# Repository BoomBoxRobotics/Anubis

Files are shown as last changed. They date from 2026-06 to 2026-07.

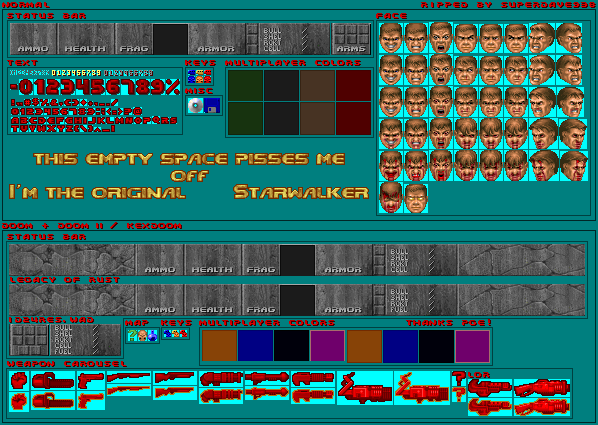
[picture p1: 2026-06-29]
Hosyond_apr24b/Games/Dungeon_Run_HUD.png

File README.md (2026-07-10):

# Anubis RC Controller Daughterboard

**A compact open-hardware support board for a DIY ESP32-S3 RC transmitter.**

Anubis is an open hardware and open firmware RC controller project built around accessible DIY parts, modern radio-control features, and a design that builders can understand, repair, modify, and improve.

This repository contains the custom daughterboard for the Anubis controller. It sits under a Hosyond 2.8 inch ESP32-S3 display board and turns the early wiring-heavy prototype into a cleaner, more repeatable hardware platform.

## Mission

The goal is simple: make a capable, repairable, hackable transmitter that is not locked behind a black box.

The first Anubis prototype used off-the-shelf modules wired together by hand: display board, power switches, regulators, analog input boards, GPIO expanders, gimbal connectors, and radio wiring. That is a great way to prove an idea, but it gets messy fast. This daughterboard pulls those support circuits onto a purpose-built PCB while leaving the Hosyond ESP32-S3 board as the main brain, display, touch interface, and firmware target.

Anubis is meant for experimentation as much as use. Builders should be able to change pin mappings, adapt connectors, swap radio hardware, and tune the firmware for their own transmitter layout.

## At A Glance

| Area | Current Direction |
| --- | --- |
| Main controller | Hosyond 2.8 inch ESP32-S3 display/dev board |
| Battery system | 2S LiPo or two 18650 cells as a 2S pack |
| Charging input | USB-C 5 V input, 500 mA to 1.5 A charge target |
| Switched outputs | `+5V_SW` and `+3V3_SW` accessory rails |
| Analog inputs | Two onboard ADS1115 ADCs, up to 8 analog channels |
| GPIO expansion | MCP23017 16-bit I2C GPIO expander |
| Radio paths | ELRS/CRSF over UART and optional ESP-NOW |
| Assembly goal | As much JLCPCB assembly as practical |
| Project status | Prototype hardware, ready for assembled-board validation |

## Core Design Goals

- Use common, hobby-accessible parts where possible.
- Keep the project open enough for community modification.
- Support modern RC workflows such as ELRS and ESP-NOW.
- Reduce hand wiring compared with the early prototype.
- Make the board practical for JLCPCB assembly.
- Keep external accessory power switchable from firmware.
- Leave room for manual wiring where real-world modules and harnesses vary.

## Hardware Overview

The daughterboard adds the support electronics around the Hosyond ESP32-S3 board:

- USB-C 5 V input for charging and power input.
- Standard 2S LiPo balance connector for the battery pack.
- Support for a 2S LiPo pack or two 18650 cells configured as a 2S pack.
- 2S battery gauge/protection circuitry based around `BQ28Z610DRZR-R1`.
- R14 high-side protection path using two JLC-available `CSD18502Q5B` N-FETs, with the charger and buck regulators fed from protected `BAT_SYS`.
- Switched 5 V rail for UART/ELRS-side accessories.
- Switched 3.3 V rail for I2C, analog, and low-voltage peripherals.
- Two Pololu mini pushbutton power switch modules for rail control.
- Two onboard ADS1115 ADC circuits for up to eight analog inputs.
- One onboard MCP23017 GPIO expander for buttons and digital expansion.
- JST and pin-header breakouts for UART, I2C, GPIO, gimbals, and accessories.
- ESD protection for external signal connections.
- Ground plane and wider routing rules for higher-current power paths.

## Power Rails

| Rail | Intended Use | Approximate Max Current |
| --- | --- | --- |
| USB-C input | 5 V charge/input source | 500 mA to 1.5 A charge target |
| `+5V_SW` | ELRS/UART-side accessory power | about 1 A |
| `+3V3_SW` | I2C, ADCs, MCP23017, gimbals, sensors | about 500 mA |

The switched rails are controlled through the two Pololu #2808 mini pushbutton power switch modules. The ESP32-S3 can shut down attached devices without relying on the attached devices to behave nicely.

## Firmware Map

The main Anubis firmware runs on the Hosyond ESP32-S3 board. Current daughterboard-aware firmware support includes:

- Touchscreen UI for transmitter settings.
- Model storage and configuration.
- Stick calibration.
- Expo, rates, trims, endpoints, failsafe, and mixing.
- ELRS/CRSF support over UART.
- ESP-NOW transmitter support.
- Dual ADS1115 support for onboard analog inputs at `0x48` and `0x49`.
- MCP23017 GPIO expander support at `0x20`.
- Battery monitoring and deep-sleep behavior.

### Pin Assignments

| Function | ESP32-S3 Pin |
| --- | --- |
| I2C SDA | GPIO16 |
| I2C SCL | GPIO15 |
| ELRS/UART TX | GPIO44 |
| ELRS/UART RX | GPIO43 |
| Battery ADC | GPIO9 |
| 5 V rail switch control | GPIO2 |
| 3.3 V rail switch control | GPIO3 |
| Deep-sleep/wake button sense | GPIO14 |
| Deep-sleep/wake button reference | GPIO21 |

GPIO2 and GPIO3 control the two Pololu rail-switch modules. GPIO14 and GPIO21 route to the two-pin deep-sleep/wake pushbutton header. UART-to-ELRS wiring can still be crossed manually if a specific module harness expects the opposite order.

### I2C Devices

| Device | Address | Role |
| --- | --- | --- |
| ADS1115 primary | `0x48` | Four gimbal/stick analog axes |
| ADS1115 auxiliary | `0x49` | Spare analog inputs |
| MCP23017 | `0x20` | GPIO expansion and active-low button/switch inputs |
| BQ25887 charger | `0x6B` | 2S charger status and pack voltage reporting |

## Board Connection Reference

The following tables describe the designators and nets on the R14 PCB. Pin numbers are the KiCad footprint pin numbers and should be checked against connector orientation and pin-1 markings before making a cable.

### Electrical Test Pads

| Pad | Net | Signal source or intended measurement |
| --- | --- | --- |
| `TP1` | `USB_VBUS` | USB-C `J1` VBUS, before input fuse `F1` |
| `TP2` | `CHG_IN` | Fused USB input after `F1`; charger `U1` pin 23 |
| `TP3` | `BAT_SYS` | Protected battery/system bus feeding charger `U1` BAT pins and the 5 V/3.3 V regulators |
| `TP4` | `CELL_MID` | 2S pack midpoint from `J7` pin 2; charger `U1` pin 9 sense connection |
| `TP5` | `BAT_SYS` | Second protected battery/system-bus test point; electrically the same as `TP3` |
| `TP6` | `+5V` | Unswitched 5 V regulator output after `L1`, before Pololu switch `SW1` |
| `TP7` | `+3V3` | Unswitched 3.3 V regulator output after `L2`, before Pololu switch `SW2` |
| `TP9` | `+3V3_SW` | Switched 3.3 V output from `SW2` |
| `TP10` | `CHG_STAT` | Charger `U1` pin 2 charge-status output; also drives status LED `D2` |
| `TP11` | `PG_STAT` | Charger `U1` pin 1 power-good output; also drives status LED `D3` |
| `TP12` | `BATT_RAW_N` | Raw pack negative from `J7` pin 1, on the battery side of current-sense resistor `R46` |
| `TP13` | `BATT_RAW_P` | Raw pack positive from `J7` pin 3 |
| `TP14` | `GND` | System ground, on the system side of current-sense resistor `R46` |
| `TP15` | `AIN4` | Auxiliary ADC `U6` (`0x49`) AIN0, pin 4 |
| `TP16` | `AIN5` | Auxiliary ADC `U6` (`0x49`) AIN1, pin 5 |
| `TP17` | `AIN6` | Auxiliary ADC `U6` (`0x49`) AIN2, pin 6 |
| `TP18` | `AIN7` | Auxiliary ADC `U6` (`0x49`) AIN3, pin 7 |

`TP8` is not fitted on the R14 PCB. Use `J30` or `J4` pin 1 to access `+5V_SW`. Also note that `BATT_RAW_N` and `GND` are separated by the 2 mOhm current-sense resistor; do not treat `TP12` and `TP14` as interchangeable measurement points.

### Hosyond Manual Solder Pads

These pads replace the original `J3` connector so individual wires from the Hosyond board can be soldered directly to the daughterboard.

| Pad | Net | Hosyond/source mapping |
| --- | --- | --- |
| `J30` | `+5V_SW` | Switched 5 V output from `SW1`; also available at `J4` pin 1 |
| `J31` | `UART_TX` | Hosyond ESP32-S3 GPIO44; routed to `J4` pin 3 |
| `J32` | `UART_RX` | Hosyond ESP32-S3 GPIO43; routed to `J4` pin 4 |
| `J33` | `I2C_SDA` | Hosyond ESP32-S3 GPIO16; shared daughterboard I2C data bus |
| `J34` | `I2C_SCL` | Hosyond ESP32-S3 GPIO15; shared daughterboard I2C clock bus |
| `J35` | `GPIO2` | Hosyond ESP32-S3 GPIO2; drives `SW1` 5 V control through `R17` |
| `J36` | `GPIO3` | Hosyond ESP32-S3 GPIO3; drives `SW2` 3.3 V control through `R18` |
| `J37` | `GPIO14` | Hosyond ESP32-S3 GPIO14; routed to wake-button header `J6` pin 1 |
| `J38` | `GPIO21` | Hosyond ESP32-S3 GPIO21; routed to wake-button header `J6` pin 2 |
| `J39` | `GND` | Daughterboard system ground |

### MCP23017 Manual Solder Pads

The `EXP_*` GPIO pads are on the protected external side of a 100 ohm series resistor and an ESD array. `U7` is the MCP23017 at I2C address `0x20`.

| Pad | Net | Source |
| --- | --- | --- |
| `J91` | `EXP_GPA0` | `U7` GPA0 pin 21 through `R23`; ESD `D4` |
| `J92` | `EXP_GPA1` | `U7` GPA1 pin 22 through `R24`; ESD `D4` |
| `J93` | `EXP_GPA2` | `U7` GPA2 pin 23 through `R25`; ESD `D4` |
| `J94` | `EXP_GPA3` | `U7` GPA3 pin 24 through `R26`; ESD `D4` |
| `J95` | `EXP_GPA4` | `U7` GPA4 pin 25 through `R27`; ESD `D5` |
| `J96` | `EXP_GPA5` | `U7` GPA5 pin 26 through `R28`; ESD `D5` |
| `J97` | `EXP_GPA6` | `U7` GPA6 pin 27 through `R29`; ESD `D5` |
| `J98` | `EXP_GPA7` | `U7` GPA7 pin 28 through `R30`; ESD `D5` |
| `J99` | `EXP_GPB0` | `U7` GPB0 pin 1 through `R31`; ESD `D6` |
| `J910` | `EXP_GPB1` | `U7` GPB1 pin 2 through `R32`; ESD `D6` |
| `J911` | `EXP_GPB2` | `U7` GPB2 pin 3 through `R33`; ESD `D6` |
| `J912` | `EXP_GPB3` | `U7` GPB3 pin 4 through `R34`; ESD `D6` |
| `J913` | `EXP_GPB4` | `U7` GPB4 pin 5 through `R35`; ESD `D7` |
| `J914` | `EXP_GPB5` | `U7` GPB5 pin 6 through `R36`; ESD `D7` |
| `J915` | `EXP_GPB6` | `U7` GPB6 pin 7 through `R37`; ESD `D7` |
| `J916` | `EXP_GPB7` | `U7` GPB7 pin 8 through `R38`; ESD `D7` |
| `J925` | `MCP_INTA` | `U7` INTA pin 20 with pull-up `R43` |
| `J926` | `MCP_INTB` | `U7` INTB pin 19 with pull-up `R44` |
| `J927` | `MCP_RESET` | `U7` RESET pin 18 with pull-up `R42` and capacitor `C29` |
| `J928` | `+3V3_SW_LOGIC` | Switched 3.3 V logic rail after isolation link `R45` |
| `J929` | `GND` | Daughterboard system ground |

### Connector Pinouts

| Connector | Purpose | Pinout |
| --- | --- | --- |
| `J1` | USB-C 5 V input | A5 = `CC1`; B5 = `CC2`; A9/B9 = `USB_VBUS`; A12/B12 = `GND`; shield tabs = `GND` |
| `J4` | 5-pin UART JST-GH, top-entry, 1.25 mm | 1 = `+5V_SW`; 2 = `GND`; 3 = `UART_TX`; 4 = `UART_RX`; 5 = `GND` |
| `J5` | 4-pin I2C through-hole header, 2.54 mm | 1 = `+3V3_SW`; 2 = `GND`; 3 = `I2C_SDA`; 4 = `I2C_SCL` |
| `J6` | 2-pin deep-sleep/wake button header, 2.54 mm | 1 = `GPIO14`; 2 = `GPIO21`; a momentary button connects the two pins |
| `J7` | 2S balance input, side-entry JST-XH, 2.50 mm | 1 = `BATT_RAW_N`; 2 = `CELL_MID`; 3 = `BATT_RAW_P` |
| `J8` | Left gimbal A, 3-pin JST-GH, 1.25 mm | 1 = `GND`; 2 = `AIN0`; 3 = `+3V3_SW` |
| `J40` | Left gimbal B, 3-pin JST-GH, 1.25 mm | 1 = `GND`; 2 = `AIN1`; 3 = `+3V3_SW` |
| `J41` | Right gimbal A, 3-pin JST-GH, 1.25 mm | 1 = `GND`; 2 = `AIN2`; 3 = `+3V3_SW` |
| `J42` | Right gimbal B, 3-pin JST-GH, 1.25 mm | 1 = `GND`; 2 = `AIN3`; 3 = `+3V3_SW` |

`J2` is a schematic-only switched-power-output symbol and has no footprint on the R14 PCB. `J3` is not a physical connector; its signals are implemented as solder pads `J30` through `J39`. JST-GH mounting pads marked `MP` are mechanical and have no electrical connection.

### Pololu Power-Switch Module Headers

| Header | Pin 1 | Pin 2 | Pin 3 | Pin 4 |
| --- | --- | --- | --- | --- |
| `SW1` Pololu #2808 5 V switch | `+5V` input | `+5V_SW` output | `GND` | `CTRL_5V_SW` |
| `SW2` Pololu #2808 3.3 V switch | `+3V3` input | `+3V3_SW` output | `GND` | `CTRL_3V3_SW` |

## Control Hardware

The controller is designed around parts that are easy for hobby builders to source or substitute:

- Hosyond 2.8 inch ESP32-S3 display board as the main controller.
- RadioMaster Pocket/Zorro X5-style gimbals.
- ELRS module support through UART/CRSF.
- Optional ESP-NOW receiver support for WiFi-equipped ESP32 receivers.
- D-pad/button input through the MCP23017 GPIO expander.
- Auxiliary analog inputs through the ADS1115 circuits.

The mechanical layout fits around the Hosyond board and controller shell constraints. The Hosyond board sits above the daughterboard on standoffs, with the daughterboard occupying the surrounding and lower internal space.

## Repository Contents

| Path | Purpose |
| --- | --- |
| `Daughterboard.kicad_pro` | KiCad project file |
| `Daughterboard.kicad_sch` | Main schematic |
| `Daughterboard.kicad_pcb` | PCB layout |
| `Daughterboard.kicad_sym` | Project symbols |
| `Daughterboard.pretty/` | Custom KiCad footprints |
| `Daughterboard.net` | Exported netlist |
| `Daughterboard_pcb_bom.csv` | Human-readable PCB BOM |
| `Daughterboard_current_jlc_part_audit.csv` | JLC part audit/reference |
| `fabrication/` | Fabrication and assembly outputs |
| `daughterboard2.dxf` | Board outline reference |
| `Daughterboardv2.step` | Mechanical board reference |
| `PROJECT_CONTEXT.md` | Detailed working context for future development |

Current fabrication package:

```text
fabrication/jlcpcb_2026-07-10_r14.zip
```

Assembly files are included under:

```text
fabrication/jlcpcb_2026-07-10_r14/assembly/
```

## Manufacturing Notes

The board is being prepared for JLCPCB assembly with as many populated parts as practical. The Pololu mini pushbutton power switch modules are treated as separately installed modules. Some through-hole headers may also be hand-installed unless through-hole assembly is explicitly ordered.

Before ordering boards, always check:

- KiCad ERC and DRC reports.
- Copper clearance and board-edge clearance.
- Unrouted nets.
- Connector orientation.
- IC pin 1 orientation.
- JLCPCB part availability.
- BOM and CPL alignment in the JLCPCB preview.

Known current status from the active R14 working files:

- ERC reports no errors or warnings.
- Q1/Q2 are now JLC-available `CSD18502Q5B` FETs using project-local TI DNK/VSON-CLIP footprints.
- The R14 topology audit passes: USB-C ground, charger/system bus, high-side protection FETs, current-sense resistor, and SRP/SRN polarity all match the corrected battery-protection intent.
- The PCB has been rerouted after the Q1/Q2 footprint swap and the GND zone has been refilled.
- DRC currently reports 40 known non-connectivity items and 0 unconnected pads/items.
- JLC assembly still needs confirmed selections for `R49` and `R50`.
- Silkscreen warnings should not normally prevent fabrication.
- Copper, drill, outline, missing-net, and footprint-orientation issues should be treated as critical.

## Battery And Power Safety

This board works with lithium battery packs and charging/protection circuitry. Mistakes can damage hardware or create a safety hazard.

Do not assume a PCB revision is safe just because the schematic opens or the Gerbers generate. Review the battery path, charger configuration, protection FETs, current limits, connector polarity, and pack wiring before connecting real cells.

Use protected cells or a known-good 2S pack during testing. Current-limit the first power-up and verify rails with a meter before plugging in the Hosyond board or radio hardware.

## Project Status

This hardware is still a prototype until assembled boards are tested.

Open work includes:

- Validate the physical PCB after manufacturing.
- Confirm all connector orientations in the assembled board.
- Test the updated firmware GPIO assignments against the first assembled daughterboard.
- Verify 2S battery reporting and charger/fuel-gauge behavior on hardware.
- Confirm the auxiliary ADS1115 inputs and MCP23017 pads behave as expected with real devices attached.
- Test ELRS and ESP-NOW behavior in the finished controller.
- Document assembly steps after the first successful build.

## Contributing

Anubis is meant to be community driven. Contributions are welcome in the form of firmware changes, PCB review, mechanical improvements, documentation, testing notes, alternate part suggestions, and build reports.

If you change the hardware, include enough context for another builder to understand why the change was made. If you change the firmware, document the pin assumptions and hardware revision you tested against.

## Companion Project

The firmware and receiver-side code for the broader Anubis controller project are hosted with the main project:

```text
https://github.com/BoomBoxRobotics/Anubis
```

This daughterboard is one hardware path toward that larger goal: a capable open source RC controller that builders can actually understand, repair, and make their own.

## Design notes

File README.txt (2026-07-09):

# Anubis RC Controller Daughterboard

Anubis is an open hardware and open firmware RC controller project built around accessible DIY parts, modern radio-control features, and a design that can be modified by the community instead of locked behind a black box.

This repository contains the custom daughterboard for the Anubis controller. The board is designed to sit under a Hosyond 2.8 inch ESP32-S3 display board and turn the wiring-heavy prototype into a cleaner, more repeatable hardware platform.

The goal is simple: make a capable, repairable, hackable transmitter that builders can assemble, understand, modify, and improve.

## Why This Board Exists

The first version of Anubis used off-the-shelf modules wired together by hand: display board, power switches, regulators, analog input boards, GPIO expanders, gimbal connectors, and radio wiring. That approach is great for proving an idea, but it gets messy quickly.

This daughterboard replaces that loose wiring with a purpose-built PCB. It provides battery power management, switched accessory rails, onboard analog and GPIO expansion, and connector breakouts for the controller hardware. The Hosyond ESP32-S3 board remains the main brain and user interface, while this board handles the support electronics around it.

Anubis is intended for experimentation as much as use. Builders should be able to change pin mappings, swap modules, adapt connectors, and tune the firmware for their own transmitter layout.

## Core Design Goals

- Use common, hobby-accessible parts where possible.
- Keep the project open enough for community modification.
- Support modern RC workflows such as ELRS and ESP-NOW.
- Reduce hand wiring compared with the early prototype.
- Make the board practical for JLCPCB assembly.
- Keep power to external accessories switchable so the controller can shut down attached devices cleanly.
- Leave room for manual wiring where real-world modules and harnesses vary.

## Current Hardware Overview

The daughterboard is designed around the Hosyond 2.8 inch ESP32-S3 display/dev board. The Hosyond board provides the ESP32-S3, TFT display, touch input, USB programming interface, audio hardware, battery ADC input, UART, I2C, and expansion GPIO.

The daughterboard adds:

- USB-C 5 V input for charging/power input.
- 2S battery connection through a standard 2S LiPo balance connector.
- Support for a 2S LiPo pack or two 18650 cells configured as a 2S pack.
- 2S battery gauge/protection circuitry based around `BQ28Z610DRZR-R1`.
- Dual-FET protection/power path using `CSD83325L`.
- Switched 5 V rail for UART/ELRS-side accessories.
- Switched 3.3 V rail for I2C, analog, and low-voltage peripherals.
- Two Pololu mini pushbutton power switch modules for rail control.
- Two onboard ADS1115 ADC circuits for up to eight analog inputs.
- One onboard MCP23017 GPIO expander for buttons and digital expansion.
- JST and pin-header breakouts for UART, I2C, GPIO, gimbals, and accessory wiring.
- ESD protection for external signal connections.
- Ground plane and wider routing rules for higher-current power paths.

The current rail targets are:

| Rail | Intended Use | Approximate Max Current |
| --- | --- | --- |
| USB-C input | 5 V charge/input source | 500 mA to 1.5 A charge target |
| `+5V_SW` | ELRS/UART-side accessory power | about 1 A |
| `+3V3_SW` | I2C, ADCs, MCP23017, gimbals, sensors | about 500 mA |

## Firmware Relationship

The daughterboard is part of the larger Anubis controller project. The main firmware lives in the companion Anubis firmware project and runs on the Hosyond ESP32-S3 board.

The firmware currently includes:

- Touchscreen UI for transmitter settings.
- Model storage and configuration.
- Stick calibration.
- Expo, rates, trims, endpoints, failsafe, and mixing.
- ELRS/CRSF support over UART.
- ESP-NOW transmitter support.
- ADS1115 analog stick input support.
- MCP23017/PCF8575-style button and accessory support.
- Battery monitoring and deep-sleep behavior.

Current important firmware pin expectations include:

| Function | ESP32-S3 Pin |
| --- | --- |
| I2C SDA | GPIO16 |
| I2C SCL | GPIO15 |
| ELRS/UART TX | GPIO44 |
| ELRS/UART RX | GPIO43 |
| Battery ADC | GPIO9 |

Some pin assignments are intentionally flexible. For example, GPIO2/GPIO3 and GPIO14/GPIO21 may be reassigned in software depending on how the physical daughterboard and front-panel controls are wired. Likewise, UART-to-ELRS wiring can be crossed manually if a specific module harness expects the opposite order.

## Radio and Control Hardware

The controller is being designed around parts that are easy for hobby builders to source or substitute:

- Hosyond 2.8 inch ESP32-S3 display board as the main controller.
- RadioMaster Pocket/Zorro X5-style gimbals.
- ELRS module support through UART/CRSF.
- Optional ESP-NOW receiver support for WiFi-equipped ESP32 receivers.
- D-pad/button input through the MCP23017 GPIO expander.
- Auxiliary analog inputs through the ADS1115 circuits.

The mechanical layout is designed to fit around the Hosyond board and controller shell constraints. The Hosyond board sits above the daughterboard on standoffs, with the daughterboard occupying the surrounding and lower internal space.

## Repository Contents

Important project files:

| Path | Purpose |
| --- | --- |
| `Daughterboard.kicad_pro` | KiCad project file |
| `Daughterboard.kicad_sch` | Main schematic |
| `Daughterboard.kicad_pcb` | PCB layout |
| `Daughterboard.kicad_sym` | Project symbols |
| `Daughterboard.pretty/` | Custom KiCad footprints |
| `Daughterboard.net` | Exported netlist |
| `Daughterboard_pcb_bom.csv` | Human-readable PCB BOM |
| `Daughterboard_current_jlc_part_audit.csv` | JLC part audit/reference |
| `fabrication/` | Current fabrication and assembly outputs |
| `daughterboard2.dxf` | Board outline reference |
| `Daughterboardv2.step` | Mechanical board reference |
| `PROJECT_CONTEXT.md` | Detailed working context for future development |

Current fabrication package:

```text
fabrication/jlcpcb_2026-07-06_r12.zip
```

This package is intended for JLCPCB board fabrication. Assembly files are included under:

```text
fabrication/jlcpcb_2026-07-06_r12/assembly/
```

## Manufacturing Notes

The board is being prepared for JLCPCB assembly with as many populated parts as practical. The Pololu mini pushbutton power switch modules are treated as separately installed modules. Some through-hole headers may also be hand-installed unless through-hole assembly is explicitly ordered.

Before ordering boards, always check:

- KiCad ERC and DRC reports.
- Copper clearance and board-edge clearance.
- Unrouted nets.
- Connector orientation.
- IC pin 1 orientation.
- JLCPCB part availability.
- BOM and CPL alignment in the JLCPCB preview.

Known current status from the latest R12 fabrication pass:

- ERC reports no errors or warnings.
- DRC contains known/accepted clearance and silkscreen warnings.
- The known clearance items are around the battery-management IC package and are small differences from the configured rule.
- Silkscreen warnings should not normally prevent fabrication.
- Copper, drill, outline, missing-net, and footprint-orientation issues should be treated as critical.

## Battery and Power Safety

This board works with lithium battery packs and charging/protection circuitry. That means mistakes can damage hardware or create a safety hazard.

Do not assume a PCB revision is safe just because the schematic opens or the Gerbers generate. Review the battery path, charger configuration, protection FETs, current limits, connector polarity, and pack wiring before connecting real cells.

Use protected cells or a known-good 2S pack during testing, current-limit the first power-up, and verify rails with a meter before plugging in the Hosyond board or radio hardware.

## Project Status

This hardware is still a work in progress. The current board has been through several schematic, layout, footprint, BOM, and JLCPCB preparation passes, but it should still be treated as a prototype until assembled boards are tested.

Open work includes:

- Validate the physical PCB after manufacturing.
- Confirm all connector orientations in the assembled board.
- Update firmware for the final GPIO assignments.
- Update firmware battery handling for the 2S power system.
- Add or refine support for the second ADS1115 if all eight analog inputs are used.
- Test ELRS and ESP-NOW behavior in the finished controller.
- Document assembly steps after the first successful build.

## Contributing

Anubis is meant to be community driven. Contributions are welcome in the form of firmware changes, PCB review, mechanical improvements, documentation, testing notes, alternate part suggestions, and build reports.

If you change the hardware, include enough context for another builder to understand why the change was made. If you change the firmware, document the pin assumptions and hardware revision you tested against.

## Companion Project

The firmware and receiver-side code for the broader Anubis controller project are hosted with the main project:

```text
https://github.com/BoomBoxRobotics/Anubis
```

This daughterboard is one hardware path toward that larger goal: a capable open source RC controller that builders can actually understand, repair, and make their own.

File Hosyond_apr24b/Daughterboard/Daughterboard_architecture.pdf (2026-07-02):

1 | 2 | 3 | 4 | 5 | 6 | 7 | 8
1 | 2 | 3 | 4 | 5 | 6 | 7 | 8

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
Size: A3 | Rev: A-first-pass | F Date: 2026-06-30
KiCad E.D.A. 10.0.3 | Id: 1/1

## Title: USB-C 1S2P 18650 Power Board

### File: Daughterboard.kicad_sch

### Sheet: /

## Daughterboard

Architecture schematic: USB-C, 1S2P charge, 5V/1A, 3V3/500mA.

First pass; finalize passives and footprints before PCB.

switched load power +3V3_SW @ 500mA +5V_SW @ 1A OUTPUTS

# J2Power outputs

GPIO pulse on CTRL pushbutton power switch POLOLU | #2808
SW1 Pololu #2808 | 5V switch

1 A max output 5 V boost TPS61023 U3

TPS61023 5V | >=3 A continuous margin OV/UV/OCP/short BQ2970 + back-to-back FETs PACK PROTECTION
A2BQ2970 + dual NFET | matched cells only per-cell fuse/PTC 1S2P pack

2x 18650

BT1

2x 18650 1S2P

### CC1/CC2: 5.1k Rd 5 V sink only USB-C RECEPTACLE

J1USB-C 5V Sink

1.5A adapter mode Fuse + TVS + CIN

### INPUT PROTECTION

A1

Fuse + VBUS TVS + CIN

TS: 10k NTC

I_CHG <= 1.5 A 1S charger + power path

BQ24074

# U1BQ24074RGT

500 mA max output 3.3 V buck-boost TPS63031 U4

TPS63031 3V3

GPIO pulse on CTRL pushbutton power switch POLOLU | #2808
SW2 Pololu #2808 | 3V3 switch

GPIO3 -> CTRL_3V3_SW

GPIO2 -> CTRL_5V_SW

### ESP32-S3 GPIO

J3Hosyond ESP32-S3 GPIO

USB_VBUS | +5V CTRL_5V_SW
CTRL_3V3_SW | +3V3 BAT_SYS Design limits: - Charge current: 1.5 A max - 5 V rail: 1 A max - 3.3 V rail: 500 mA max - Full-load battery current estimate at 3.3 V pack: about 2.24 A plus transients - Use matched, voltage-balanced 18650 cells only USB-C note: plain 5.1k CC pulldowns make this a 5 V sink. For fixed 1.5 A input current, use a capable USB-C adapter, add a 500 mA / 1.5 A selector, or add Type-C current-detect/PD circuitry before drawing adapter-level current. Output power switching: Pololu #2808 modules sit after the regulators. ESP32 GPIOs pulse CTRL high to turn on, pulse CTRL low to turn off, then return to input/high-Z. Suggested pins: GPIO2 for 5 V, GPIO3 for 3.3 V.
PACK_P / PACK_N | BATT_RAW_P / BATT_RAW_N | +5V_SW
CHG_IN | +3V3_SW

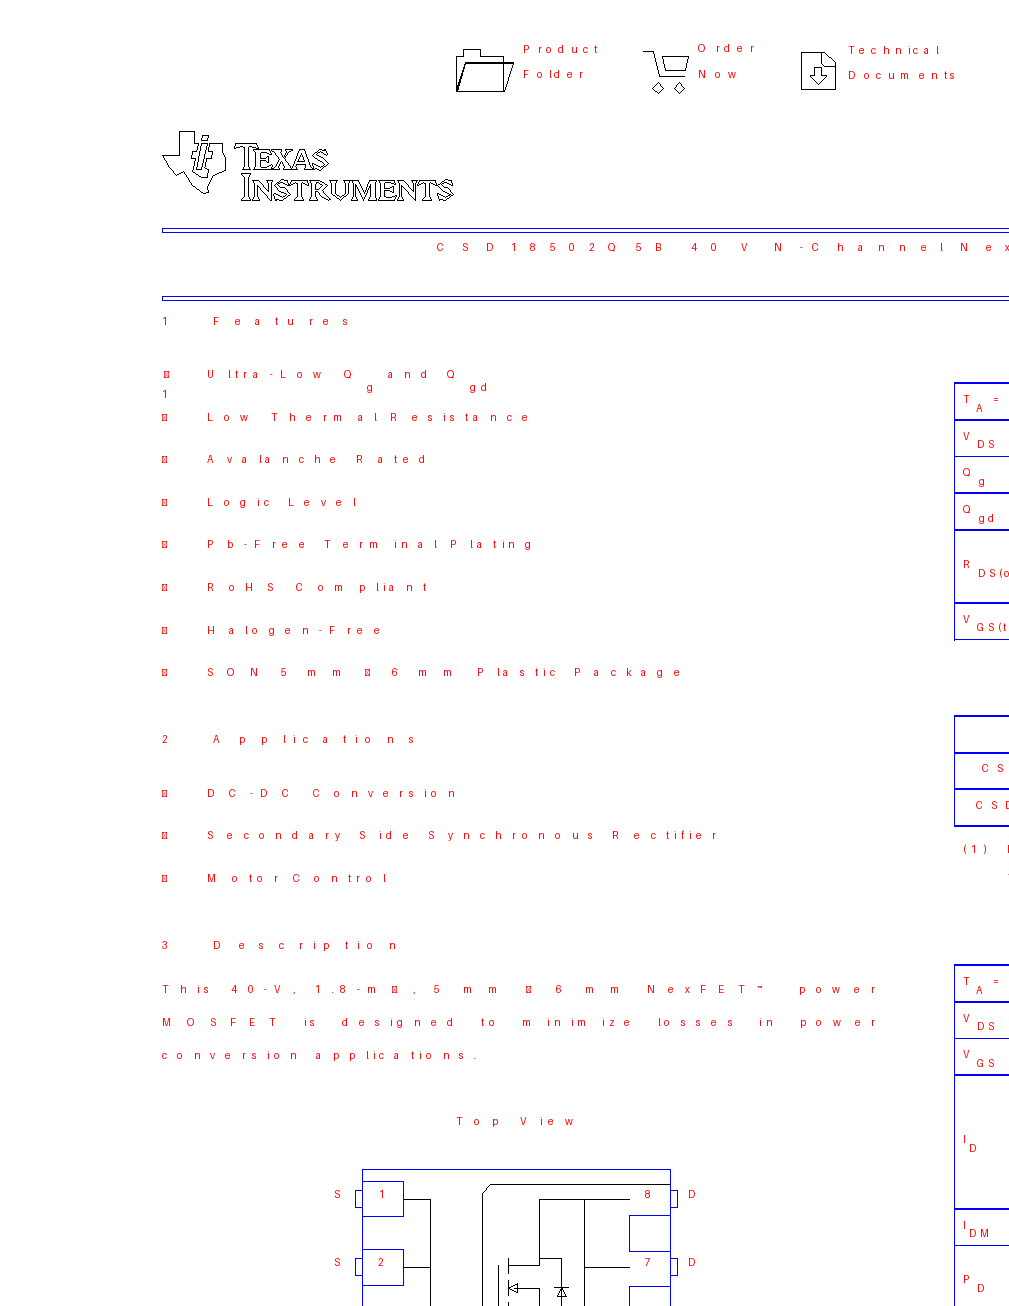
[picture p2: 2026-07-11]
Daughterboard/tmp_csd18502_page1_pinout.png

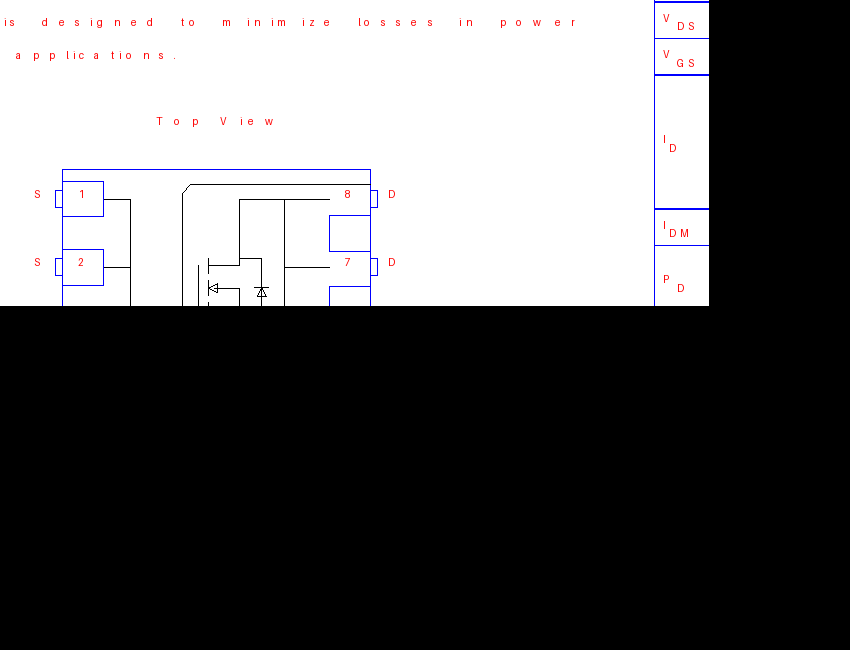
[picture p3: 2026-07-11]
Daughterboard/tmp_csd18502_pinout_crop.png

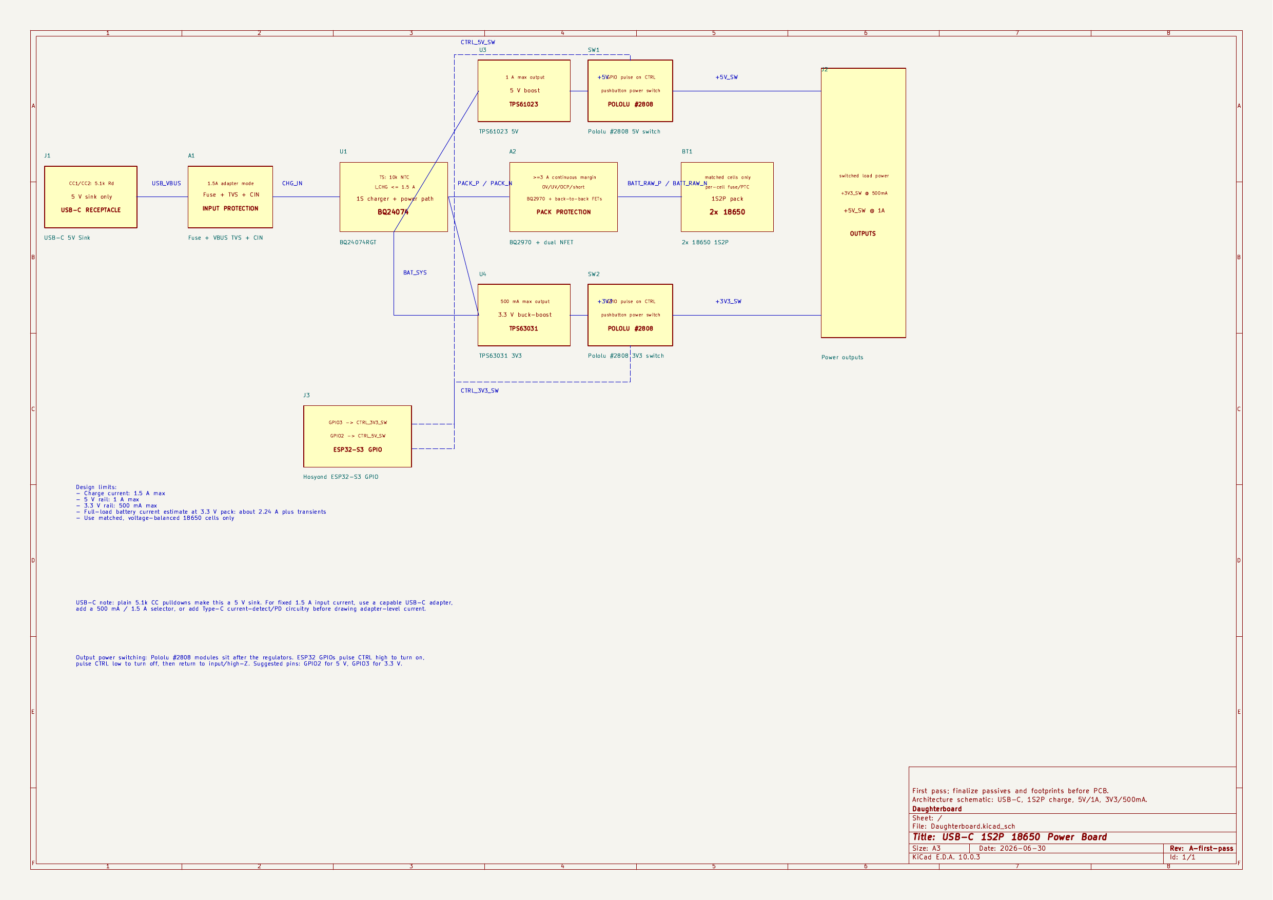
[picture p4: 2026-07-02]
Hosyond_apr24b/Daughterboard/Daughterboard_architecture_preview-1.png

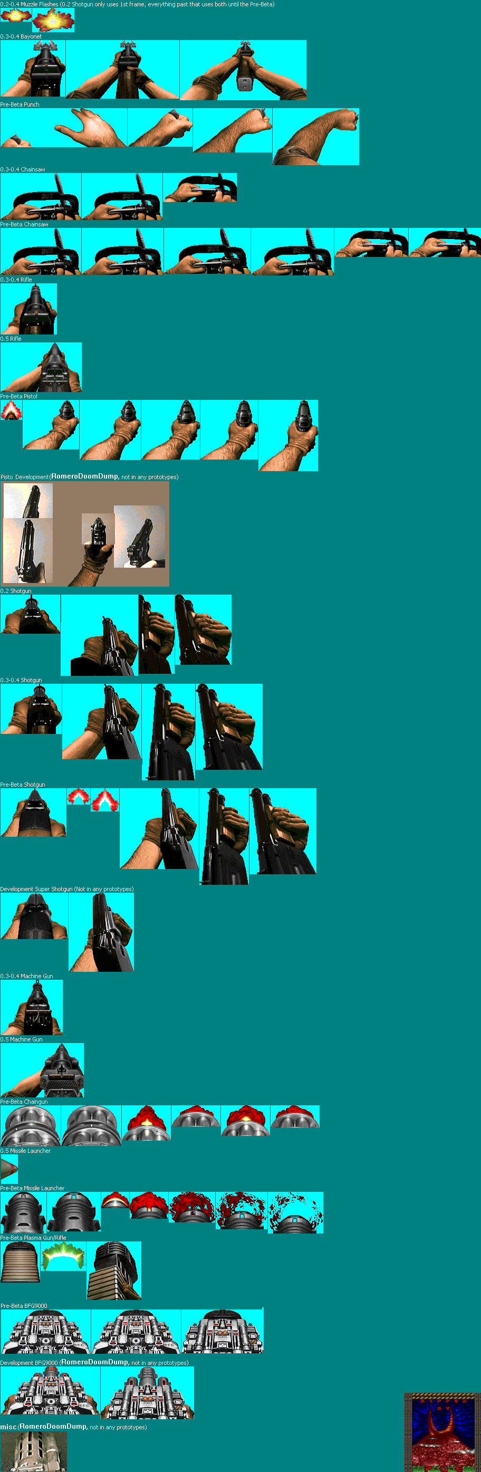
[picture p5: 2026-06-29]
Hosyond_apr24b/Games/Dungeon_Run_Weapons_Held.png

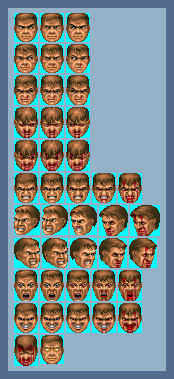
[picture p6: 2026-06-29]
Hosyond_apr24b/Games/Dungeon_Run_Face.png

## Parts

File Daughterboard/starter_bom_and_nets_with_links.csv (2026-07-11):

Section | Reference | Part / Value | Footprint | Nets | Notes | Purchase Link
USB-C input | J1 | USB-C 5V Sink | Connector_USB:USB_C_Receptacle_GCT_USB4125-xx-x_6P_TopMnt_Horizontal | CC1,CC2,GND,USB_VBUS | Power-only sink; CC1/CC2 each have 5.1k Rd to GND. | https://www.digikey.com/en/products/result?keywords=GCT+USB4125+USB-C+receptacle+6+pin
USB-C input | R1 | 5.1k 1% | Resistor_SMD:R_0603_1608Metric | CC1,GND | USB-C Rd. | https://www.digikey.com/en/products/result
USB-C input | R2 | 5.1k 1% | Resistor_SMD:R_0603_1608Metric | CC2,GND | USB-C Rd. | https://www.digikey.com/en/products/result
USB-C input | F1 | 2A hold polyfuse | Fuse:Fuse_1206_3216Metric | CHG_IN,USB_VBUS | Input fuse/polyfuse; choose exact SMD PTC/fuse current rating before layout. | https://www.digikey.com/en/products/result?keywords=2A+hold+polyfuse+resettable+fuse+PTC+SMD
USB-C input | D1 | 5V VBUS TVS | Diode_SMD:D_SOD-323 | CHG_IN,GND | Place close to USB-C connector. | https://www.digikey.com/en/products/result?keywords=5V+VBUS+TVS+SOD-323+TVS+diode
USB-C input | C1 | 10uF 10V X5R | Capacitor_SMD:C_0805_2012Metric | CHG_IN,GND | Charger input bulk. | https://www.digikey.com/en/products/result
USB-C input | C2 | 100nF 10V X7R | Capacitor_SMD:C_0603_1608Metric | CHG_IN,GND | Charger input bypass. | https://www.digikey.com/en/products/result
2S charger | U1 | BQ25887RGE 2S charger | Package_DFN_QFN:Texas_RGE0024H_VQFN-24-1EP_4x4mm_P0.5mm_EP2.7x2.7mm | BAT_SYS,BTST,CBSET,CELL_MID,CHG_IN,CHG_STAT,CHG_SW,GND,I2C_SCL,I2C_SDA,ILIM,PG_STAT,PMID,REGN,TS | USB 5V boost-mode charger connected on the protected/system side of the BQ28Z610 high-side FETs. | https://www.digikey.com/en/products/result?keywords=BQ25887RGE
2S charger | L3 | 1uH >=4A sat | Inductor_SMD:L_APV_ANR5040 | CHG_SW,PMID | BQ25887 boost-charge SMD inductor; finalize DCR/current from layout and charge limit. | https://www.digikey.com/en/products/result?keywords=1uH+%3E%3D4A+sat+shielded+inductor+SMD
2S charger | R3 | 806R 1% TBD | Resistor_SMD:R_0603_1608Metric | GND,ILIM | Input-current hardware limit target no more than 1.5A; set charge current in BQ25887 firmware/registers between 500mA and 1.5A. | https://www.digikey.com/en/products/result?keywords=0603+resistor+1%25
2S charger | R4 | TBD 1% | Resistor_SMD:R_0603_1608Metric | CBSET,GND | Cell-balance setting resistor; choose from BQ25887 datasheet. | https://www.digikey.com/en/products/result?keywords=0603+resistor+1%25
2S charger | C3 | 22uF 16V X5R | Capacitor_SMD:C_0805_2012Metric | GND,PMID | PMID bulk capacitor. | https://www.digikey.com/en/products/result
2S charger | C4 | 100nF 16V X7R | Capacitor_SMD:C_0603_1608Metric | GND,PMID | PMID HF bypass. | https://www.digikey.com/en/products/result
2S charger | C5 | 22uF 16V X5R | Capacitor_SMD:C_0805_2012Metric | BAT_SYS,GND | 2S charger BAT bulk capacitor on protected/system-side pack positive. | https://www.digikey.com/en/products/result
2S charger | C6 | 4.7uF 6.3V X5R | Capacitor_SMD:C_0603_1608Metric | GND,REGN | REGN regulator capacitor. | https://www.digikey.com/en/products/result
2S charger | C7 | 100nF 16V X7R | Capacitor_SMD:C_0603_1608Metric | BTST,CHG_SW | Bootstrap capacitor. | https://www.digikey.com/en/products/result
2S charger | C8 | 100nF 10V X7R | Capacitor_SMD:C_0603_1608Metric | CBSET,GND | CBSET filter placeholder; verify final requirement. | https://www.digikey.com/en/products/result
2S charger | C9 | 100nF 16V X7R | Capacitor_SMD:C_0603_1608Metric | BATT_RAW_P,CELL_MID | Upper-cell raw-pack sense bypass; place close to charger/protection sense pins. | https://www.digikey.com/en/products/result
2S charger | C10 | 100nF 16V X7R | Capacitor_SMD:C_0603_1608Metric | BATT_RAW_N,CELL_MID | Lower-cell raw-pack sense bypass; place close to charger/protection sense pins. | https://www.digikey.com/en/products/result
2S charger | TH1 | 10k NTC | Resistor_SMD:R_0603_1608Metric | GND,TS | 0603 NTC; place against or near the selected pack/cells. | https://www.digikey.com/en/products/result?keywords=10k+NTC+0603+NTC+thermistor
2S charger | R5 | 10k 1% | Resistor_SMD:R_0603_1608Metric | REGN,TS | TS bias; verify with selected NTC curve and BQ25887 TS thresholds. | https://www.digikey.com/en/products/result
2S charger | R6 | 2.2k | Resistor_SMD:R_0603_1608Metric | LED_CHG_A,REGN | Charge-status LED resistor. | https://www.digikey.com/en/products/result?keywords=2.2k+Resistor_SMD%3AR_0603_1608Metric+resistor
2S charger | D2 | LED green | LED_SMD:LED_0603_1608Metric | CHG_STAT,LED_CHG_A | STAT open-drain LED. | https://www.digikey.com/en/products/result?keywords=LED+green+0603+LED
2S charger | R7 | 2.2k | Resistor_SMD:R_0603_1608Metric | LED_PGOOD_A,REGN | Power-good LED resistor. | https://www.digikey.com/en/products/result?keywords=2.2k+Resistor_SMD%3AR_0603_1608Metric+resistor
2S charger | D3 | LED blue | LED_SMD:LED_0603_1608Metric | LED_PGOOD_A,PG_STAT | PG open-drain LED. | https://www.digikey.com/en/products/result?keywords=LED+blue+0603+LED
Battery | BT1 | 18650 Cell 1 lower |  | BATT_RAW_N,CELL1_P | Lower series cell holder: negative to raw pack negative, positive through F2 to CELL_MID. | https://www.digikey.com/en/products/result?keywords=18650+battery+holder+single+cell+PCB
Battery | BT2 | 18650 Cell 2 upper |  | CELL2_P,CELL_MID | Upper series cell holder: negative to CELL_MID, positive through F3 to BATT_RAW_P. | https://www.digikey.com/en/products/result?keywords=18650+battery+holder+single+cell+PCB
Battery | F2 | PTC/fuse cell1 | Fuse:Fuse_1206_3216Metric | CELL1_P,CELL_MID | SMD cell fuse/PTC; place close to lower cell positive. | https://www.digikey.com/en/products/result?keywords=PTC%2Ffuse+cell1+resettable+fuse+PTC+SMD
Battery | F3 | PTC/fuse cell2 | Fuse:Fuse_1206_3216Metric | BATT_RAW_P,CELL2_P | SMD cell fuse/PTC; place close to upper cell positive. | https://www.digikey.com/en/products/result?keywords=PTC%2Ffuse+cell2+resettable+fuse+PTC+SMD
Battery | J7 | 2S balance input JST-XH side-entry | Connector_JST:JST_XH_S3B-XH-A_1x03_P2.50mm_Horizontal | BATT_RAW_N,BATT_RAW_P,CELL_MID | Top-edge side-entry 2S balance connector pinout: B-, cell midpoint, B+. Pin 3 is raw cell-stack positive before high-side protection FETs. | https://www.digikey.com/en/products/result?keywords=JST+XH+3+pin+horizontal+S3B-XH-A
2S protection | U2 | BQ28Z610DRZR-R1 | Daughterboard:BQ28Z610_DRZ0012A_12SON_2.5x4mm_P0.5mm | BATT_RAW_N,BQ_CHG,BQ_DSG,BQ_PACK,BQ_PBI,BQ_SRN,BQ_SRP,I2C_SCL,I2C_SDA,PROT_VC,PROT_VDD,TS | TI 1S/2S gas gauge and primary protection controller wired for the high-side N-FET topology from the BQ28Z610 reference design. | https://www.digikey.com/en/products/detail/texas-instruments/BQ28Z610DRZR-R1/11625468
2S protection | R14 | 470R 1% | Resistor_SMD:R_0603_1608Metric | BATT_RAW_P,PROT_VDD | BQ28Z610 VC2 input resistor; place near U2 and verify with cell-balance routing. | https://www.digikey.com/en/products/result
2S protection | R15 | 470R 1% | Resistor_SMD:R_0603_1608Metric | CELL_MID,PROT_VC | BQ28Z610 VC1 input resistor; place near U2 and verify with cell-balance routing. | https://www.digikey.com/en/products/result
2S protection | C25 | 100nF 16V X7R | Capacitor_SMD:C_0603_1608Metric | PROT_VC,PROT_VDD | BQ28Z610 upper-cell sense filter capacitor. | https://www.digikey.com/en/products/result
2S protection | C26 | 100nF 16V X7R | Capacitor_SMD:C_0603_1608Metric | BATT_RAW_N,PROT_VC | BQ28Z610 lower-cell sense filter capacitor. | https://www.digikey.com/en/products/result
2S protection | R16 | 100R | Resistor_SMD:R_0603_1608Metric | BAT_SYS,BQ_PACK | BQ28Z610 PACK input series resistor from protected/system-side pack positive. | https://www.digikey.com/en/products/result?keywords=100R+Resistor_SMD%3AR_0603_1608Metric+resistor
2S protection | C30 | 2.2uF 10V X5R | Capacitor_SMD:C_0603_1608Metric | BATT_RAW_N,BQ_PBI | BQ28Z610 PBI hold-up capacitor; place close to U2. | https://www.digikey.com/en/products/result
2S protection | R46 | 2mR 1% 50ppm | Resistor_SMD:R_1206_3216Metric | BATT_RAW_N,GND | BQ28Z610 series current-sense resistor in the pack-negative return path; Kelvin route both ends. | https://www.digikey.com/en/products/result
2S protection | R47 | 100R | Resistor_SMD:R_0603_1608Metric | BQ_SRN,GND | BQ28Z610 SRN input filter resistor; Kelvin route from system/pack-negative side of R46. | https://www.digikey.com/en/products/result?keywords=100R+Resistor_SMD%3AR_0603_1608Metric+resistor
2S protection | R48 | 100R | Resistor_SMD:R_0603_1608Metric | BATT_RAW_N,BQ_SRP | BQ28Z610 SRP input filter resistor; Kelvin route from raw-cell-negative side of R46. | https://www.digikey.com/en/products/result?keywords=100R+Resistor_SMD%3AR_0603_1608Metric+resistor
2S protection | C31 | 100nF 16V X7R | Capacitor_SMD:C_0603_1608Metric | BQ_SRN,BQ_SRP | BQ28Z610 differential SRN/SRP filter capacitor; place close to U2. | https://www.digikey.com/en/products/result
2S protection | R21 | 100R | Resistor_SMD:R_0603_1608Metric | BQ_DSG,DO_GATE | Small series gate resistor for BQ28Z610 discharge FET control. | https://www.digikey.com/en/products/result?keywords=100R+Resistor_SMD%3AR_0603_1608Metric+resistor
2S protection | R22 | 100R | Resistor_SMD:R_0603_1608Metric | BQ_CHG,CO_GATE | Small series gate resistor for BQ28Z610 charge FET control. | https://www.digikey.com/en/products/result?keywords=100R+Resistor_SMD%3AR_0603_1608Metric+resistor
2S protection | Q1 | CSD18502Q5B charge FET | Daughterboard:CSD18502Q5B_DNK0008A_VSON-CLIP_5x6mm | BAT_SYS,CO_GATE,FET_SRC_COMMON | High-side charge-blocking N-FET; drain on protected/system side, source at the common high-side FET node. | https://jlcpcb.com/partdetail/TexasInstruments-CSD18502Q5B/C473915
2S protection | Q2 | CSD18502Q5B discharge FET | Daughterboard:CSD18502Q5B_DNK0008A_VSON-CLIP_5x6mm | DO_GATE,FET_BATT_P,FET_SRC_COMMON | High-side discharge-blocking N-FET; drain feeds the raw cell-stack positive through F4. | https://jlcpcb.com/partdetail/TexasInstruments-CSD18502Q5B/C473915
2S protection | R50 | 10M | Resistor_SMD:R_0603_1608Metric | CO_GATE,FET_SRC_COMMON | Gate-source bleed for the high-side charge FET. | https://www.digikey.com/en/products/result?keywords=10M+Resistor_SMD%3AR_0603_1608Metric+resistor
2S protection | R49 | 10M | Resistor_SMD:R_0603_1608Metric | DO_GATE,FET_SRC_COMMON | Gate-source bleed for the high-side discharge FET. | https://www.digikey.com/en/products/result?keywords=10M+Resistor_SMD%3AR_0603_1608Metric+resistor
2S protection | C32 | 100nF 25V X7R | Capacitor_SMD:C_0603_1608Metric | BAT_SYS,FET_SRC_COMMON | ESD/transient capacitor across charge FET per BQ28Z610 layout guidance. | https://www.digikey.com/en/products/result
2S protection | C33 | 100nF 25V X7R | Capacitor_SMD:C_0603_1608Metric | FET_BATT_P,FET_SRC_COMMON | ESD/transient capacitor across discharge FET per BQ28Z610 layout guidance. | https://www.digikey.com/en/products/result
Battery | F4 | 2A battery path fuse | Fuse:Fuse_1206_3216Metric | BATT_RAW_P,FET_BATT_P | SMD high-side pack fuse between protection FETs and raw cell-stack positive. | https://www.digikey.com/en/products/result?keywords=2A+battery+path+fuse+resettable+fuse+PTC+SMD
5V buck | U3 | AP63200WU 5V Buck | Package_TO_SOT_SMD:TSOT-23-6 | BAT_SYS,BST_5V,EN_5V,FB_5V,GND,SW_5V | 2S-to-5V buck regulator; 5V / 1A target. | https://www.digikey.com/en/products/result?keywords=AP63200WU
5V buck | L1 | 4.7uH >=3A sat | Inductor_SMD:L_APV_ANR4020 | +5V,SW_5V | Low-DCR shielded SMD inductor. | https://www.digikey.com/en/products/result?keywords=4.7uH+%3E%3D3A+sat+shielded+inductor+SMD
5V buck | C11 | 10uF 16V X5R | Capacitor_SMD:C_0805_2012Metric | BAT_SYS,GND | Input bulk. | https://www.digikey.com/en/products/result
5V buck | C12 | 100nF 16V X7R | Capacitor_SMD:C_0603_1608Metric | BAT_SYS,GND | Input bypass. | https://www.digikey.com/en/products/result
5V buck | C13 | 22uF 10V X5R | Capacitor_SMD:C_0805_2012Metric | +5V,GND | Output bulk. | https://www.digikey.com/en/products/result
5V buck | C14 | 22uF 10V X5R | Capacitor_SMD:C_0805_2012Metric | +5V,GND | Output bulk. | https://www.digikey.com/en/products/result
5V buck | C15 | 100nF 16V X7R | Capacitor_SMD:C_0603_1608Metric | BST_5V,SW_5V | Bootstrap capacitor. | https://www.digikey.com/en/products/result
5V buck | R8 | 523k 1% | Resistor_SMD:R_0603_1608Metric | +5V,FB_5V | Feedback top for 5V from 0.8V reference. | https://www.digikey.com/en/products/result
5V buck | R9 | 100k 1% | Resistor_SMD:R_0603_1608Metric | FB_5V,GND | Feedback bottom. | https://www.digikey.com/en/products/result
5V buck | R10 | 100k | Resistor_SMD:R_0603_1608Metric | BAT_SYS,EN_5V | Default 5V buck enabled when pack is present. | https://www.digikey.com/en/products/result?keywords=100k+Resistor_SMD%3AR_0603_1608Metric+resistor
3V3 buck | U4 | AP63200WU 3V3 Buck | Package_TO_SOT_SMD:TSOT-23-6 | BAT_SYS,BST_3V3,EN_3V3,FB_3V3,GND,SW_3V3 | 2S-to-3.3V buck regulator; 3.3V / 500mA target. | https://www.digikey.com/en/products/result?keywords=AP63200WU
3V3 buck | L2 | 4.7uH >=2A sat | Inductor_SMD:L_APV_ANR4020 | +3V3,SW_3V3 | Low-DCR shielded SMD inductor. | https://www.digikey.com/en/products/result?keywords=4.7uH+%3E%3D2A+sat+shielded+inductor+SMD
3V3 buck | C16 | 10uF 16V X5R | Capacitor_SMD:C_0805_2012Metric | BAT_SYS,GND | Input bulk. | https://www.digikey.com/en/products/result
3V3 buck | C21 | 100nF 16V X7R | Capacitor_SMD:C_0603_1608Metric | BAT_SYS,GND | Input bypass. | https://www.digikey.com/en/products/result
3V3 buck | C22 | 22uF 10V X5R | Capacitor_SMD:C_0805_2012Metric | +3V3,GND | Output cap. | https://www.digikey.com/en/products/result
3V3 buck | C23 | 22uF 10V X5R | Capacitor_SMD:C_0805_2012Metric | +3V3,GND | Output cap. | https://www.digikey.com/en/products/result
3V3 buck | C24 | 100nF 16V X7R | Capacitor_SMD:C_0603_1608Metric | BST_3V3,SW_3V3 | Bootstrap capacitor. | https://www.digikey.com/en/products/result
3V3 buck | R11 | 316k 1% | Resistor_SMD:R_0603_1608Metric | +3V3,FB_3V3 | Feedback top for 3.3V from 0.8V reference. | https://www.digikey.com/en/products/result
3V3 buck | R12 | 100k 1% | Resistor_SMD:R_0603_1608Metric | FB_3V3,GND | Feedback bottom. | https://www.digikey.com/en/products/result
3V3 buck | R13 | 100k | Resistor_SMD:R_0603_1608Metric | BAT_SYS,EN_3V3 | Default 3.3V buck enabled when pack is present. | https://www.digikey.com/en/products/result?keywords=100k+Resistor_SMD%3AR_0603_1608Metric+resistor
Output switching | SW1 | Pololu #2808 5V switch | Daughterboard:Pololu_2808_Raised_Header | +5V,+5V_SW,CTRL_5V_SW,GND | VIN=+5V, VOUT=+5V_SW. | https://www.pololu.com/product/2808
Output switching | SW2 | Pololu #2808 3V3 switch | Daughterboard:Pololu_2808_Raised_Header | +3V3,+3V3_SW,CTRL_3V3_SW,GND | VIN=+3V3, VOUT=+3V3_SW. | https://www.pololu.com/product/2808
Output switching | R17 | 330R | Resistor_SMD:R_0603_1608Metric | CTRL_5V_SW,GPIO2 | Series resistor from ESP32 GPIO2. | https://www.digikey.com/en/products/result?keywords=330R+Resistor_SMD%3AR_0603_1608Metric+resistor
Output switching | R18 | 330R | Resistor_SMD:R_0603_1608Metric | CTRL_3V3_SW,GPIO3 | Series resistor from ESP32 GPIO3. | https://www.digikey.com/en/products/result?keywords=330R+Resistor_SMD%3AR_0603_1608Metric+resistor
Control | J30 | J3P Hosyond +5V_SW solder pad | TestPoint:TestPoint_Pad_1.5x1.5mm | +5V_SW | Individual solder-wire pad for wire from Hosyond ESP32-S3 board.
Control | J31 | J3A Hosyond UART_TX solder pad | TestPoint:TestPoint_Pad_1.5x1.5mm | UART_TX | Individual solder-wire pad for wire from Hosyond ESP32-S3 board.
Control | J32 | J3B Hosyond UART_RX solder pad | TestPoint:TestPoint_Pad_1.5x1.5mm | UART_RX | Individual solder-wire pad for wire from Hosyond ESP32-S3 board.
Control | J33 | J3C Hosyond I2C_SDA solder pad | TestPoint:TestPoint_Pad_1.5x1.5mm | I2C_SDA | Individual solder-wire pad for wire from Hosyond ESP32-S3 board.
Control | J34 | J3D Hosyond I2C_SCL solder pad | TestPoint:TestPoint_Pad_1.5x1.5mm | I2C_SCL | Individual solder-wire pad for wire from Hosyond ESP32-S3 board.
Control | J35 | J3E Hosyond GPIO2 solder pad | TestPoint:TestPoint_Pad_1.5x1.5mm | GPIO2 | Individual solder-wire pad for wire from Hosyond ESP32-S3 board.
Control | J36 | J3F Hosyond GPIO3 solder pad | TestPoint:TestPoint_Pad_1.5x1.5mm | GPIO3 | Individual solder-wire pad for wire from Hosyond ESP32-S3 board.
Control | J37 | J3G Hosyond GPIO14 solder pad | TestPoint:TestPoint_Pad_1.5x1.5mm | GPIO14 | Individual solder-wire pad for wire from Hosyond ESP32-S3 board.
Control | J38 | J3H Hosyond GPIO21 solder pad | TestPoint:TestPoint_Pad_1.5x1.5mm | GPIO21 | Individual solder-wire pad for wire from Hosyond ESP32-S3 board.
Control | J39 | J3I Hosyond GND solder pad | TestPoint:TestPoint_Pad_1.5x1.5mm | GND | Individual solder-wire pad for wire from Hosyond ESP32-S3 board.
Outputs | J2 | Switched power outputs |  | +3V3_SW,+5V_SW,GND | External switched-load connector. | https://www.digikey.com/en/products/result?keywords=2.54mm+pin+header+vertical+3+position
Signals | J4 | UART JST-GH 1.25mm | Connector_JST:JST_GH_SM05B-GHS-TB_1x05-1MP_P1.25mm_Horizontal | +5V_SW,GND,UART_RX,UART_TX | 5-pin 1.25mm JST UART header: +5V_SW,GND,TX,RX,GND. | https://www.digikey.com/en/products/result?keywords=SM05B-GHS-TB+JST+GH+5+position
Signals | J5 | I2C male header 2.54mm | Connector_PinHeader_2.54mm:PinHeader_1x04_P2.54mm_Vertical | +3V3_SW,GND,I2C_SCL,I2C_SDA | 4-pin 2.54mm I2C header: +3V3_SW,GND,SDA,SCL. | https://www.digikey.com/en/products/result?keywords=2.54mm+pin+header+vertical+4+position
Signals | J6 | Deep sleep pushbutton header | Connector_PinHeader_2.54mm:PinHeader_1x02_P2.54mm_Vertical | GPIO14,GPIO21 | 2-pin 2.54mm header for pushbutton between GPIO14 and GPIO21. | https://www.digikey.com/en/products/result?keywords=2.54mm+pin+header+vertical+2+position
Analog inputs | U5 | ADS1115IDGS 0x48 | Package_SO:TSSOP-10_3x3mm_P0.5mm | +3V3_SW_LOGIC,AIN0,AIN1,AIN2,AIN3,GND,I2C_SCL,I2C_SDA | First 4-channel ADS1115; ADDR=GND for I2C address 0x48. | https://www.digikey.com/en/products/result?keywords=ADS1115IDGS
Analog inputs | U6 | ADS1115IDGS 0x49 | Package_SO:TSSOP-10_3x3mm_P0.5mm | +3V3_SW_LOGIC,AIN4,AIN5,AIN6,AIN7,GND,I2C_SCL,I2C_SDA | Second 4-channel ADS1115; ADDR=VDD for I2C address 0x49. | https://www.digikey.com/en/products/result?keywords=ADS1115IDGS
Analog inputs | R19 | 4.7k | Resistor_SMD:R_0603_1608Metric | +3V3_SW_LOGIC,I2C_SDA | Local I2C SDA pullup for switched onboard ADCs. | https://www.digikey.com/en/products/result?keywords=4.7k+Resistor_SMD%3AR_0603_1608Metric+resistor
Analog inputs | R20 | 4.7k | Resistor_SMD:R_0603_1608Metric | +3V3_SW_LOGIC,I2C_SCL | Local I2C SCL pullup for switched onboard ADCs. | https://www.digikey.com/en/products/result?keywords=4.7k+Resistor_SMD%3AR_0603_1608Metric+resistor
Analog inputs | C17 | 100nF 10V X7R | Capacitor_SMD:C_0603_1608Metric | +3V3_SW_LOGIC,GND | U5 local VDD bypass. | https://www.digikey.com/en/products/result
Analog inputs | C18 | 1uF 10V X5R | Capacitor_SMD:C_0603_1608Metric | +3V3_SW_LOGIC,GND | U5 local supply bulk. | https://www.digikey.com/en/products/result
Analog inputs | C19 | 100nF 10V X7R | Capacitor_SMD:C_0603_1608Metric | +3V3_SW_LOGIC,GND | U6 local VDD bypass. | https://www.digikey.com/en/products/result
Analog inputs | C20 | 1uF 10V X5R | Capacitor_SMD:C_0603_1608Metric | +3V3_SW_LOGIC,GND | U6 local supply bulk. | https://www.digikey.com/en/products/result
Analog inputs | J8 | Left gimbal A JST-GH 1.25mm | Connector_JST:JST_GH_BM03B-GHS-TBT_1x03-1MP_P1.25mm_Vertical | +3V3_SW,AIN0,GND | 3-pin gimbal potentiometer input: GND,AIN0,+3V3_SW. | https://www.digikey.com/en/products/result?keywords=2.54mm+pin+header+vertical+10+position
Analog inputs | J40 | Left gimbal B JST-GH 1.25mm | Connector_JST:JST_GH_BM03B-GHS-TBT_1x03-1MP_P1.25mm_Vertical | +3V3_SW,AIN1,GND | 3-pin gimbal potentiometer input: GND,AIN1,+3V3_SW. | https://www.digikey.com/en/products/result
Analog inputs | J41 | Right gimbal A JST-GH 1.25mm | Connector_JST:JST_GH_BM03B-GHS-TBT_1x03-1MP_P1.25mm_Vertical | +3V3_SW,AIN2,GND | 3-pin gimbal potentiometer input: GND,AIN2,+3V3_SW. | https://www.digikey.com/en/products/result
Analog inputs | J42 | Right gimbal B JST-GH 1.25mm | Connector_JST:JST_GH_BM03B-GHS-TBT_1x03-1MP_P1.25mm_Vertical | +3V3_SW,AIN3,GND | 3-pin gimbal potentiometer input: GND,AIN3,+3V3_SW. | https://www.digikey.com/en/products/result
Analog inputs | R45 | 0R | Resistor_SMD:R_0603_1608Metric | +3V3_SW,+3V3_SW_LOGIC | Net-tie jumper: heavy switched 3.3V rail to light local ADC/MCP logic branch. | https://www.digikey.com/en/products/result?keywords=0R+Resistor_SMD%3AR_0603_1608Metric+resistor
GPIO expander | U7 | MCP23017-E/SO | Daughterboard:SOIC-28W_7.5x17.9mm_P1.27mm_NoPads11_14 | +3V3_SW_LOGIC,GND,I2C_SCL,I2C_SDA,MCP_A0,MCP_A1,MCP_A2,MCP_GPA0,MCP_GPA1,MCP_GPA2,MCP_GPA3,MCP_GPA4,MCP_GPA5,MCP_GPA6,MCP_GPA7,MCP_GPB0,MCP_GPB1,MCP_GPB2,MCP_GPB3,MCP_GPB4,MCP_GPB5,MCP_GPB6,MCP_GPB7,MCP_INTA,MCP_INTB,MCP_RESET | 16-bit I2C GPIO expander at address 0x20; powered from the light +3V3_SW_LOGIC branch. Treat GPA7/GPB7 as output-only unless the selected MCP23017 variant is verified. | https://www.digikey.com/en/products/result?keywords=MCP23017-E%2FSO
GPIO expander | C27 | 100nF 10V X7R | Capacitor_SMD:C_0603_1608Metric | +3V3_SW_LOGIC,GND | MCP23017 local VDD bypass, place close to U7. | https://www.digikey.com/en/products/result
GPIO expander | C28 | 1uF 10V X5R | Capacitor_SMD:C_0603_1608Metric | +3V3_SW_LOGIC,GND | MCP23017 local supply bulk. | https://www.digikey.com/en/products/result
GPIO expander | R39 | 0R | Resistor_SMD:R_0603_1608Metric | GND,MCP_A0 | Default address strap low; A2:A0=000 gives I2C address 0x20. | https://www.digikey.com/en/products/result?keywords=0R+Resistor_SMD%3AR_0603_1608Metric+resistor
GPIO expander | R40 | 0R | Resistor_SMD:R_0603_1608Metric | GND,MCP_A1 | Default address strap low. | https://www.digikey.com/en/products/result?keywords=0R+Resistor_SMD%3AR_0603_1608Metric+resistor
GPIO expander | R41 | 0R | Resistor_SMD:R_0603_1608Metric | GND,MCP_A2 | Default address strap low. | https://www.digikey.com/en/products/result?keywords=0R+Resistor_SMD%3AR_0603_1608Metric+resistor
GPIO expander | R42 | 10k | Resistor_SMD:R_0603_1608Metric | +3V3_SW_LOGIC,MCP_RESET | Reset pullup to switched 3.3V logic branch. | https://www.digikey.com/en/products/result?keywords=10k+Resistor_SMD%3AR_0603_1608Metric+resistor
GPIO expander | C29 | 100nF 10V X7R | Capacitor_SMD:C_0603_1608Metric | GND,MCP_RESET | Optional reset delay/noise filter; omit if firmware needs immediate reset release. | https://www.digikey.com/en/products/result
GPIO expander | R43 | 10k | Resistor_SMD:R_0603_1608Metric | +3V3_SW_LOGIC,MCP_INTA | INTA pullup; also available on a solder pad. | https://www.digikey.com/en/products/result?keywords=10k+Resistor_SMD%3AR_0603_1608Metric+resistor
GPIO expander | R44 | 10k | Resistor_SMD:R_0603_1608Metric | +3V3_SW_LOGIC,MCP_INTB | INTB pullup; also available on a solder pad. | https://www.digikey.com/en/products/result?keywords=10k+Resistor_SMD%3AR_0603_1608Metric+resistor
GPIO expander | R23 | 100R | Resistor_SMD:R_0603_1608Metric | EXP_GPA0,MCP_GPA0 | Series resistor between MCP23017 GPIO and external solder pad. | https://www.digikey.com/en/products/result?keywords=100R+Resistor_SMD%3AR_0603_1608Metric+resistor
GPIO expander | R24 | 100R | Resistor_SMD:R_0603_1608Metric | EXP_GPA1,MCP_GPA1 | Series resistor between MCP23017 GPIO and external solder pad. | https://www.digikey.com/en/products/result?keywords=100R+Resistor_SMD%3AR_0603_1608Metric+resistor
GPIO expander | R25 | 100R | Resistor_SMD:R_0603_1608Metric | EXP_GPA2,MCP_GPA2 | Series resistor between MCP23017 GPIO and external solder pad. | https://www.digikey.com/en/products/result?keywords=100R+Resistor_SMD%3AR_0603_1608Metric+resistor
GPIO expander | R26 | 100R | Resistor_SMD:R_0603_1608Metric | EXP_GPA3,MCP_GPA3 | Series resistor between MCP23017 GPIO and external solder pad. | https://www.digikey.com/en/products/result?keywords=100R+Resistor_SMD%3AR_0603_1608Metric+resistor
GPIO expander | R27 | 100R | Resistor_SMD:R_0603_1608Metric | EXP_GPA4,MCP_GPA4 | Series resistor between MCP23017 GPIO and external solder pad. | https://www.digikey.com/en/products/result?keywords=100R+Resistor_SMD%3AR_0603_1608Metric+resistor
GPIO expander | R28 | 100R | Resistor_SMD:R_0603_1608Metric | EXP_GPA5,MCP_GPA5 | Series resistor between MCP23017 GPIO and external solder pad. | https://www.digikey.com/en/products/result?keywords=100R+Resistor_SMD%3AR_0603_1608Metric+resistor
GPIO expander | R29 | 100R | Resistor_SMD:R_0603_1608Metric | EXP_GPA6,MCP_GPA6 | Series resistor between MCP23017 GPIO and external solder pad. | https://www.digikey.com/en/products/result?keywords=100R+Resistor_SMD%3AR_0603_1608Metric+resistor
GPIO expander | R30 | 100R | Resistor_SMD:R_0603_1608Metric | EXP_GPA7,MCP_GPA7 | Series resistor between MCP23017 GPIO and external solder pad. | https://www.digikey.com/en/products/result?keywords=100R+Resistor_SMD%3AR_0603_1608Metric+resistor
GPIO expander | R31 | 100R | Resistor_SMD:R_0603_1608Metric | EXP_GPB0,MCP_GPB0 | Series resistor between MCP23017 GPIO and external solder pad. | https://www.digikey.com/en/products/result?keywords=100R+Resistor_SMD%3AR_0603_1608Metric+resistor
GPIO expander | R32 | 100R | Resistor_SMD:R_0603_1608Metric | EXP_GPB1,MCP_GPB1 | Series resistor between MCP23017 GPIO and external solder pad. | https://www.digikey.com/en/products/result?keywords=100R+Resistor_SMD%3AR_0603_1608Metric+resistor
GPIO expander | R33 | 100R | Resistor_SMD:R_0603_1608Metric | EXP_GPB2,MCP_GPB2 | Series resistor between MCP23017 GPIO and external solder pad. | https://www.digikey.com/en/products/result?keywords=100R+Resistor_SMD%3AR_0603_1608Metric+resistor
GPIO expander | R34 | 100R | Resistor_SMD:R_0603_1608Metric | EXP_GPB3,MCP_GPB3 | Series resistor between MCP23017 GPIO and external solder pad. | https://www.digikey.com/en/products/result?keywords=100R+Resistor_SMD%3AR_0603_1608Metric+resistor
GPIO expander | R35 | 100R | Resistor_SMD:R_0603_1608Metric | EXP_GPB4,MCP_GPB4 | Series resistor between MCP23017 GPIO and external solder pad. | https://www.digikey.com/en/products/result?keywords=100R+Resistor_SMD%3AR_0603_1608Metric+resistor
GPIO expander | R36 | 100R | Resistor_SMD:R_0603_1608Metric | EXP_GPB5,MCP_GPB5 | Series resistor between MCP23017 GPIO and external solder pad. | https://www.digikey.com/en/products/result?keywords=100R+Resistor_SMD%3AR_0603_1608Metric+resistor
GPIO expander | R37 | 100R | Resistor_SMD:R_0603_1608Metric | EXP_GPB6,MCP_GPB6 | Series resistor between MCP23017 GPIO and external solder pad. | https://www.digikey.com/en/products/result?keywords=100R+Resistor_SMD%3AR_0603_1608Metric+resistor
GPIO expander | R38 | 100R | Resistor_SMD:R_0603_1608Metric | EXP_GPB7,MCP_GPB7 | Series resistor between MCP23017 GPIO and external solder pad. | https://www.digikey.com/en/products/result?keywords=100R+Resistor_SMD%3AR_0603_1608Metric+resistor
GPIO expander | D4 | 4ch 3.3V GPIO TVS array TBD | Daughterboard:SOT-23-6_NoPad6 | EXP_GPA0,EXP_GPA1,EXP_GPA2,EXP_GPA3,GND | ESD protection placeholder for four exposed MCP23017 solder-pad lines; choose exact low-cap 3.3V array before layout. | https://www.digikey.com/en/products/result?keywords=4+channel+3.3V+ESD+TVS+array+SOT-23-6
GPIO expander | D5 | 4ch 3.3V GPIO TVS array TBD | Daughterboard:SOT-23-6_NoPad6 | EXP_GPA4,EXP_GPA5,EXP_GPA6,EXP_GPA7,GND | ESD protection placeholder for four exposed MCP23017 solder-pad lines; choose exact low-cap 3.3V array before layout. | https://www.digikey.com/en/products/result?keywords=4+channel+3.3V+ESD+TVS+array+SOT-23-6
GPIO expander | D6 | 4ch 3.3V GPIO TVS array TBD | Daughterboard:SOT-23-6_NoPad6 | EXP_GPB0,EXP_GPB1,EXP_GPB2,EXP_GPB3,GND | ESD protection placeholder for four exposed MCP23017 solder-pad lines; choose exact low-cap 3.3V array before layout. | https://www.digikey.com/en/products/result?keywords=4+channel+3.3V+ESD+TVS+array+SOT-23-6
GPIO expander | D7 | 4ch 3.3V GPIO TVS array TBD | Daughterboard:SOT-23-6_NoPad6 | EXP_GPB4,EXP_GPB5,EXP_GPB6,EXP_GPB7,GND | ESD protection placeholder for four exposed MCP23017 solder-pad lines; choose exact low-cap 3.3V array before layout. | https://www.digikey.com/en/products/result?keywords=4+channel+3.3V+ESD+TVS+array+SOT-23-6
GPIO expander | J91 | MCP23017 GPA0 solder pad | TestPoint:TestPoint_Pad_1.5x1.5mm | EXP_GPA0 | Individual solder-wire pad for MCP23017 GPIO/utility breakout.
GPIO expander | J92 | MCP23017 GPA1 solder pad | TestPoint:TestPoint_Pad_1.5x1.5mm | EXP_GPA1 | Individual solder-wire pad for MCP23017 GPIO/utility breakout.
GPIO expander | J93 | MCP23017 GPA2 solder pad | TestPoint:TestPoint_Pad_1.5x1.5mm | EXP_GPA2 | Individual solder-wire pad for MCP23017 GPIO/utility breakout.
GPIO expander | J94 | MCP23017 GPA3 solder pad | TestPoint:TestPoint_Pad_1.5x1.5mm | EXP_GPA3 | Individual solder-wire pad for MCP23017 GPIO/utility breakout.
GPIO expander | J95 | MCP23017 GPA4 solder pad | TestPoint:TestPoint_Pad_1.5x1.5mm | EXP_GPA4 | Individual solder-wire pad for MCP23017 GPIO/utility breakout.
GPIO expander | J96 | MCP23017 GPA5 solder pad | TestPoint:TestPoint_Pad_1.5x1.5mm | EXP_GPA5 | Individual solder-wire pad for MCP23017 GPIO/utility breakout.
GPIO expander | J97 | MCP23017 GPA6 solder pad | TestPoint:TestPoint_Pad_1.5x1.5mm | EXP_GPA6 | Individual solder-wire pad for MCP23017 GPIO/utility breakout.
GPIO expander | J98 | MCP23017 GPA7 solder pad | TestPoint:TestPoint_Pad_1.5x1.5mm | EXP_GPA7 | Individual solder-wire pad for MCP23017 GPIO/utility breakout.
GPIO expander | J99 | MCP23017 GPB0 solder pad | TestPoint:TestPoint_Pad_1.5x1.5mm | EXP_GPB0 | Individual solder-wire pad for MCP23017 GPIO/utility breakout.
GPIO expander | J910 | MCP23017 GPB1 solder pad | TestPoint:TestPoint_Pad_1.5x1.5mm | EXP_GPB1 | Individual solder-wire pad for MCP23017 GPIO/utility breakout.
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

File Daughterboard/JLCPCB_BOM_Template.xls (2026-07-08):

Comment | Designator | Footprint | JLCPCB Part#(optional)
100uF | C1 | CASE-B_3528 | C16133
100nF | C2, C9, C10 | 0603 | C14663
300KΩ | R4, R7 | 0603 | C23024
15KΩ | R5, R6 | 0603_R | C22809
100KΩ | R1, R3 | 0603_R | C25803
10uF | C3-5 | 1206_C | C13585
100Ω | R2 | 0603_R | C22775
1N4148WS | D1 | SOD-323 | C2128
LM358DR2G | U1 | SOIC-8_150mil | C7950
HT7550-1 | VR1 | SOT-89(SOT-89-3) | C16106

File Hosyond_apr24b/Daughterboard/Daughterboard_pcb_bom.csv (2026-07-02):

Refs | Value | Footprint | Qty | Description | Datasheet | Purchase Link | DNP
BT1 | 18650 Cell 1 lower |  | 1 |  |  | https://www.digikey.com/en/products/result?keywords=18650+battery+holder+single+cell+PCB
BT2 | 18650 Cell 2 upper |  | 1 |  |  | https://www.digikey.com/en/products/result?keywords=18650+battery+holder+single+cell+PCB
C1 | 10uF 10V X5R | Capacitor_SMD:C_0805_2012Metric | 1 |  |  | https://www.digikey.com/en/products/result
C2,C19,C27,C29 | 100nF 10V X7R | Capacitor_SMD:C_0603_1608Metric | 4 |  |  | https://www.digikey.com/en/products/result
C3,C5 | 22uF 16V X5R | Capacitor_SMD:C_0805_2012Metric | 2 |  |  | https://www.digikey.com/en/products/result
C4,C7,C9,C10,C12,C15,C21,C24-C26 | 100nF 16V X7R | Capacitor_SMD:C_0603_1608Metric | 10 |  |  | https://www.digikey.com/en/products/result
C6 | 4.7uF 6.3V X5R | Capacitor_SMD:C_0603_1608Metric | 1 |  |  | https://www.digikey.com/en/products/result
C11,C16 | 10uF 16V X5R | Capacitor_SMD:C_0805_2012Metric | 2 |  |  | https://www.digikey.com/en/products/result
C13,C14,C22,C23 | 22uF 10V X5R | Capacitor_SMD:C_0805_2012Metric | 4 |  |  | https://www.digikey.com/en/products/result
C17 | 100nF 10V X7R DNP | Capacitor_SMD:C_0603_1608Metric | 1 |  |  | https://www.digikey.com/en/products/result
C18,C20,C28 | 1uF 10V X5R | Capacitor_SMD:C_0603_1608Metric | 3 |  |  | https://www.digikey.com/en/products/result
D1 | 5V VBUS TVS | Diode_SMD:D_SOD-323 | 1 |  |  | https://www.digikey.com/en/products/result?keywords=5V+VBUS+TVS+SOD-323+TVS+diode
D2 | LED green | LED_SMD:LED_0603_1608Metric | 1 |  |  | https://www.digikey.com/en/products/result?keywords=LED+green+0603+LED
D3 | LED blue | LED_SMD:LED_0603_1608Metric | 1 |  |  | https://www.digikey.com/en/products/result?keywords=LED+blue+0603+LED
D4-D7 | SP0504BAHTG 4ch GPIO TVS | Daughterboard:SOT-23-6_NoPad6 | 4 |  | https://www.littelfuse.com/products/tvs-diode-arrays/low-capacitance-esd-protection/sp05.aspx | https://www.digikey.com/en/products/result?keywords=SP0504BAHTG
F1 | 2A hold polyfuse | Fuse:Fuse_1206_3216Metric | 1 |  |  | https://www.digikey.com/en/products/result?keywords=2A+hold+polyfuse+resettable+fuse+PTC+SMD
F2 | PTC/fuse cell1 | Fuse:Fuse_1206_3216Metric | 1 |  |  | https://www.digikey.com/en/products/result?keywords=PTC%2Ffuse+cell1+resettable+fuse+PTC+SMD
F3 | PTC/fuse cell2 | Fuse:Fuse_1206_3216Metric | 1 |  |  | https://www.digikey.com/en/products/result?keywords=PTC%2Ffuse+cell2+resettable+fuse+PTC+SMD
F4 | 2A system fuse | Fuse:Fuse_1206_3216Metric | 1 |  |  | https://www.digikey.com/en/products/result?keywords=2A+system+fuse+resettable+fuse+PTC+SMD
J1 | USB-C 5V Sink | Connector_USB:USB_C_Receptacle_GCT_USB4125-xx-x_6P_TopMnt_Horizontal | 1 |  |  | https://www.digikey.com/en/products/result?keywords=GCT+USB4125+USB-C+receptacle+6+pin
J2 | Switched power outputs |  | 1 |  |  | https://www.digikey.com/en/products/result?keywords=2.54mm+pin+header+vertical+3+position
J4 | UART JST-GH 1.25mm | Connector_JST:JST_GH_SM05B-GHS-TB_1x05-1MP_P1.25mm_Horizontal | 1 |  |  | https://www.digikey.com/en/products/result?keywords=SM05B-GHS-TB+JST+GH+5+position
J5 | I2C male header 2.54mm | Connector_PinHeader_2.54mm:PinHeader_1x04_P2.54mm_Vertical | 1 |  |  | https://www.digikey.com/en/products/result?keywords=2.54mm+pin+header+vertical+4+position
J6 | Deep sleep pushbutton header | Connector_PinHeader_2.54mm:PinHeader_1x02_P2.54mm_Vertical | 1 |  |  | https://www.digikey.com/en/products/result?keywords=2.54mm+pin+header+vertical+2+position
J7 | 2S balance input JST-XH | Connector_JST:JST_XH_B3B-XH-A_1x03_P2.50mm_Vertical | 1 |  |  | https://www.digikey.com/en/products/result?keywords=JST+XH+3+pin+vertical+B3B-XH-A
J8 | Analog input header | Connector_PinHeader_2.54mm:PinHeader_1x10_P2.54mm_Vertical | 1 |  |  | https://www.digikey.com/en/products/result?keywords=2.54mm+pin+header+vertical+10+position
J30 | J3P Hosyond +5V_SW solder pad | TestPoint:TestPoint_Pad_1.5x1.5mm | 1
J31 | J3A Hosyond UART_TX solder pad | TestPoint:TestPoint_Pad_1.5x1.5mm | 1
J32 | J3B Hosyond UART_RX solder pad | TestPoint:TestPoint_Pad_1.5x1.5mm | 1
J33 | J3C Hosyond I2C_SDA solder pad | TestPoint:TestPoint_Pad_1.5x1.5mm | 1
J34 | J3D Hosyond I2C_SCL solder pad | TestPoint:TestPoint_Pad_1.5x1.5mm | 1
J35 | J3E Hosyond GPIO2 solder pad | TestPoint:TestPoint_Pad_1.5x1.5mm | 1
J36 | J3F Hosyond GPIO3 solder pad | TestPoint:TestPoint_Pad_1.5x1.5mm | 1
J37 | J3G Hosyond GPIO14 solder pad | TestPoint:TestPoint_Pad_1.5x1.5mm | 1
J38 | J3H Hosyond GPIO21 solder pad | TestPoint:TestPoint_Pad_1.5x1.5mm | 1
J39 | J3I Hosyond GND solder pad | TestPoint:TestPoint_Pad_1.5x1.5mm | 1
J91 | MCP23017 GPA0 solder pad | TestPoint:TestPoint_Pad_1.5x1.5mm | 1
J92 | MCP23017 GPA1 solder pad | TestPoint:TestPoint_Pad_1.5x1.5mm | 1
J93 | MCP23017 GPA2 solder pad | TestPoint:TestPoint_Pad_1.5x1.5mm | 1
J94 | MCP23017 GPA3 solder pad | TestPoint:TestPoint_Pad_1.5x1.5mm | 1
J95 | MCP23017 GPA4 solder pad | TestPoint:TestPoint_Pad_1.5x1.5mm | 1
J96 | MCP23017 GPA5 solder pad | TestPoint:TestPoint_Pad_1.5x1.5mm | 1
J97 | MCP23017 GPA6 solder pad | TestPoint:TestPoint_Pad_1.5x1.5mm | 1
J98 | MCP23017 GPA7 solder pad | TestPoint:TestPoint_Pad_1.5x1.5mm | 1
J99 | MCP23017 GPB0 solder pad | TestPoint:TestPoint_Pad_1.5x1.5mm | 1
J910 | MCP23017 GPB1 solder pad | TestPoint:TestPoint_Pad_1.5x1.5mm | 1
J911 | MCP23017 GPB2 solder pad | TestPoint:TestPoint_Pad_1.5x1.5mm | 1
J912 | MCP23017 GPB3 solder pad | TestPoint:TestPoint_Pad_1.5x1.5mm | 1
J913 | MCP23017 GPB4 solder pad | TestPoint:TestPoint_Pad_1.5x1.5mm | 1
J914 | MCP23017 GPB5 solder pad | TestPoint:TestPoint_Pad_1.5x1.5mm | 1
J915 | MCP23017 GPB6 solder pad | TestPoint:TestPoint_Pad_1.5x1.5mm | 1
J916 | MCP23017 GPB7 solder pad | TestPoint:TestPoint_Pad_1.5x1.5mm | 1
J925 | MCP23017 INTA solder pad | TestPoint:TestPoint_Pad_1.5x1.5mm | 1
J926 | MCP23017 INTB solder pad | TestPoint:TestPoint_Pad_1.5x1.5mm | 1
J927 | MCP23017 RESET solder pad | TestPoint:TestPoint_Pad_1.5x1.5mm | 1
J928 | MCP23017 +3V3_SW solder pad | TestPoint:TestPoint_Pad_1.5x1.5mm | 1
J929 | MCP23017 GND solder pad | TestPoint:TestPoint_Pad_1.5x1.5mm | 1
L1 | 4.7uH >=3A sat | Inductor_SMD:L_APV_ANR4020 | 1 |  |  | https://www.digikey.com/en/products/result?keywords=4.7uH+%3E%3D3A+sat+shielded+inductor+SMD
L2 | 4.7uH >=2A sat | Inductor_SMD:L_APV_ANR4020 | 1 |  |  | https://www.digikey.com/en/products/result?keywords=4.7uH+%3E%3D2A+sat+shielded+inductor+SMD
L3 | 1uH >=4A sat | Inductor_SMD:L_APV_ANR5040 | 1 |  |  | https://www.digikey.com/en/products/result?keywords=1uH+%3E%3D4A+sat+shielded+inductor+SMD
Q1 | CSD83325L | Daughterboard:CSD83325L_YJE0006A | 1 |  |  | https://www.digikey.com/en/products/result?keywords=CSD83325L
R1,R2 | 5.1k 1% | Resistor_SMD:R_0603_1608Metric | 2 |  |  | https://www.digikey.com/en/products/result
R3 | 806R 1% ILIM | Resistor_SMD:R_0603_1608Metric | 1 |  |  | https://www.digikey.com/en/products/result?keywords=806+ohm+1%25+0603+resistor
R4 | 220R 1% CBSET | Resistor_SMD:R_0603_1608Metric | 1 |  |  | https://www.digikey.com/en/products/result?keywords=220+ohm+1%25+0603+resistor
R5 | 10k 1% | Resistor_SMD:R_0603_1608Metric | 1 |  |  | https://www.digikey.com/en/products/result
R6,R7 | 2.2k | Resistor_SMD:R_0603_1608Metric | 2 |  |  | https://www.digikey.com/en/products/result?keywords=2.2k+Resistor_SMD%3AR_0603_1608Metric+resistor
R8 | 523k 1% | Resistor_SMD:R_0603_1608Metric | 1 |  |  | https://www.digikey.com/en/products/result
R9,R12 | 100k 1% | Resistor_SMD:R_0603_1608Metric | 2 |  |  | https://www.digikey.com/en/products/result
R10,R13 | 100k | Resistor_SMD:R_0603_1608Metric | 2 |  |  | https://www.digikey.com/en/products/result?keywords=100k+Resistor_SMD%3AR_0603_1608Metric+resistor
R11 | 316k 1% | Resistor_SMD:R_0603_1608Metric | 1 |  |  | https://www.digikey.com/en/products/result
R14,R15 | 470R 1% | Resistor_SMD:R_0603_1608Metric | 2 |  |  | https://www.digikey.com/en/products/result
R16 | 2.0k 1% | Resistor_SMD:R_0603_1608Metric | 1 |  |  | https://www.digikey.com/en/products/result
R17,R18 | 330R | Resistor_SMD:R_0603_1608Metric | 2 |  |  | https://www.digikey.com/en/products/result?keywords=330R+Resistor_SMD%3AR_0603_1608Metric+resistor
R19,R20 | 4.7k | Resistor_SMD:R_0603_1608Metric | 2 |  |  | https://www.digikey.com/en/products/result?keywords=4.7k+Resistor_SMD%3AR_0603_1608Metric+resistor
R21-R38 | 100R | Resistor_SMD:R_0603_1608Metric | 18 |  |  | https://www.digikey.com/en/products/result?keywords=100R+Resistor_SMD%3AR_0603_1608Metric+resistor
R39-R41,R45 | 0R | Resistor_SMD:R_0603_1608Metric | 4 |  |  | https://www.digikey.com/en/products/result?keywords=0R+Resistor_SMD%3AR_0603_1608Metric+resistor
R42-R44 | 10k | Resistor_SMD:R_0603_1608Metric | 3 |  |  | https://www.digikey.com/en/products/result?keywords=10k+Resistor_SMD%3AR_0603_1608Metric+resistor
SW1 | Pololu #2808 5V switch | Daughterboard:Pololu_2808_Raised_Header | 1 |  |  | https://www.pololu.com/product/2808
SW2 | Pololu #2808 3V3 switch | Daughterboard:Pololu_2808_Raised_Header | 1 |  |  | https://www.pololu.com/product/2808
TH1 | 10k NTC | Resistor_SMD:R_0603_1608Metric | 1 |  |  | https://www.digikey.com/en/products/result?keywords=10k+NTC+0603+NTC+thermistor
TP1 | USB_VBUS test pad | TestPoint:TestPoint_Pad_D1.0mm | 1
TP2 | CHG_IN test pad | TestPoint:TestPoint_Pad_D1.0mm | 1
TP3 | PACK_P test pad | TestPoint:TestPoint_Pad_D1.0mm | 1
TP4 | CELL_MID test pad | TestPoint:TestPoint_Pad_D1.0mm | 1
TP5 | BAT_SYS test pad | TestPoint:TestPoint_Pad_D1.0mm | 1
TP6 | +5V test pad | TestPoint:TestPoint_Pad_D1.0mm | 1
TP7 | +3V3 test pad | TestPoint:TestPoint_Pad_D1.0mm | 1
TP8 | +5V_SW test pad | TestPoint:TestPoint_Pad_D1.0mm | 1
TP9 | +3V3_SW test pad | TestPoint:TestPoint_Pad_D1.0mm | 1
TP10 | CHG_STAT test pad | TestPoint:TestPoint_Pad_D1.0mm | 1
TP11 | PG_STAT test pad | TestPoint:TestPoint_Pad_D1.0mm | 1
TP12 | BATT_RAW_N test pad | TestPoint:TestPoint_Pad_D1.0mm | 1
TP13 | VM_SENSE test pad | TestPoint:TestPoint_Pad_D1.0mm | 1
TP14 | GND test pad | TestPoint:TestPoint_Pad_D1.0mm | 1
U1 | BQ25887RGE 2S charger | Package_DFN_QFN:Texas_RGE0024H_VQFN-24-1EP_4x4mm_P0.5mm_EP2.7x2.7mm | 1 |  |  | https://www.digikey.com/en/products/result?keywords=BQ25887RGE
U2 | S-8252AAH-M6T1U | Package_TO_SOT_SMD:SOT-23-6 | 1 |  |  | https://www.digikey.com/en/products/result?keywords=S-8252AAH-M6T1U
U3 | AP63200WU 5V Buck | Package_TO_SOT_SMD:TSOT-23-6 | 1 |  |  | https://www.digikey.com/en/products/result?keywords=AP63200WU
U4 | AP63200WU 3V3 Buck | Package_TO_SOT_SMD:TSOT-23-6 | 1 |  |  | https://www.digikey.com/en/products/result?keywords=AP63200WU
U5 | ADS1115IDGS 0x48 | Package_SO:TSSOP-10_3x3mm_P0.5mm | 1 |  |  | https://www.digikey.com/en/products/result?keywords=ADS1115IDGS
U6 | ADS1115IDGS 0x49 | Package_SO:TSSOP-10_3x3mm_P0.5mm | 1 |  |  | https://www.digikey.com/en/products/result?keywords=ADS1115IDGS
U7 | MCP23017-E/SO | Daughterboard:SOIC-28W_7.5x17.9mm_P1.27mm_NoPads11_14 | 1 |  |  | https://www.digikey.com/en/products/result?keywords=MCP23017-E%2FSO

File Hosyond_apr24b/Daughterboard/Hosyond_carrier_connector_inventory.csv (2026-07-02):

Ref | Name | Pin Count | KiCad Symbol | Footprint Suggestion | Pitch | Type | Notes
J1 | Hosyond UART | 4 | Connector_Generic:Conn_01x04 | Connector_JST:JST_SH_B4B-ZR_1x04_P1.00mm_Horizontal | 1.25mm or verify actual | JST cable connector | Pins: 5V,GND,UART_TX,UART_RX. Footprint suggestion must be changed if connector is JST-GH/JST-SH 1.25mm.
J2 | Hosyond I2C | 4 | Connector_Generic:Conn_01x04 | Connector_JST:JST_SH_B4B-ZR_1x04_P1.00mm_Horizontal | 1.25mm or verify actual | JST cable connector | Pins: 3V3,GND,I2C_SCL,I2C_SDA. Verify exact JST family before layout.
J3 | Hosyond GPIO | 4 | Connector_Generic:Conn_01x04 | Connector_JST:JST_SH_B4B-ZR_1x04_P1.00mm_Horizontal | 1.25mm or verify actual | JST cable connector | Pins: GPIO2,GPIO3,GPIO14,GPIO21. GPIO14/21 now rail enables.
J4 | Left Gimbal | 6 | Connector_Generic:Conn_01x06 | Connector_JST:JST_SH_B6B-ZR_1x06_P1.00mm_Horizontal | 1.25mm or verify actual | JST cable connector | Pins: GND,L_X,3V3,GND,L_Y,3V3.
J5 | Right Gimbal | 6 | Connector_Generic:Conn_01x06 | Connector_JST:JST_SH_B6B-ZR_1x06_P1.00mm_Horizontal | 1.25mm or verify actual | JST cable connector | Pins: GND,R_X,3V3,GND,R_Y,3V3.
J6 | ELRS Module | 4 | Connector_Generic:Conn_01x04 | Connector_PinHeader_2.54mm:PinHeader_1x04_P2.54mm_Vertical | 2.54mm | module/header | Pins: 5V_SW,GND,RX,TX. Use footprint matching actual ELRS socket/header.
J7 | USB-C Breakout | 6 | Connector_Generic:Conn_01x06 | Connector_PinHeader_2.54mm:PinHeader_1x06_P2.54mm_Vertical | 2.54mm | module/header | Pins: VBUS,GND,CC1,D-,D+,CC2. Breakout handles CC resistors.
J8 | Battery Input/Pass-through | 2 | Connector_Generic:Conn_01x02 | Connector_JST:JST_PH_B2B-PH-K_1x02_P2.00mm_Vertical | 2.0mm typical | JST battery connector | Protected 1S LiPo only. Verify actual battery/Hosyond connector.
J9 | 3V3 I2C Power Switch Output Side | 7 | Connector_Generic:Conn_01x07 | Connector_PinHeader_2.54mm:PinHeader_1x07_P2.54mm_Vertical | 2.54mm | Pololu/module header | Other side of 3.3V switch module. Pins should carry 3V3_SW/GND where the Pololu board exposes switched VOUT/GND; unused pads can be NC.
J10 | 5V ELRS Power Switch Output Side | 7 | Connector_Generic:Conn_01x07 | Connector_PinHeader_2.54mm:PinHeader_1x07_P2.54mm_Vertical | 2.54mm | Pololu module header | Other side of 5V switch module. Pins should carry 5V_SW/GND where the Pololu board exposes switched VOUT/GND; unused pads can be NC.
J11 | Power Button | 2 | Connector_Generic:Conn_01x02 | Connector_JST:JST_SH_B2B-ZR_1x02_P1.00mm_Horizontal | 1.25mm or verify actual | JST/button connector | Pins: GPIO2 sense, GPIO3 reference. Direct ESP32 connection for deep-sleep wake.
J12 | Power Button LED | 2 | Connector_Generic:Conn_01x02 | Connector_JST:JST_SH_B2B-ZR_1x02_P1.00mm_Horizontal | 1.25mm or verify actual | JST/LED connector | LED+ from PCF8575 P05 through resistor if needed; LED- to GND.
J13 | Aux Analog A0/A1 Header | 6 | Connector_Generic:Conn_01x06 | Connector_JST:JST_SH_B6B-ZR_1x06_P1.00mm_Horizontal | 1.25mm or verify actual | JST aux analog connector | Pins: GND,A0_B,3V3,GND,A1_B,3V3.
J14 | 5-way D-pad | 7 | Connector_Generic:Conn_01x07 | Connector_PinHeader_2.54mm:PinHeader_1x07_P2.54mm_Vertical | 2.54mm | module/header | Pins: SELECT,D,C,B,A,VCC,GND. Map to PCF P00-P04.
J15 | Hosyond USB Pads/Header | 4 | Connector_Generic:Conn_01x04 | Connector_PinHeader_2.54mm:PinHeader_1x04_P2.54mm_Vertical | TBD | pads/header | Pins: VBUS,GND,D-,D+. Use if breaking USB out through carrier.
J16 | Hosyond Battery Pads/Header | 2 | Connector_Generic:Conn_01x02 | Connector_PinHeader_2.54mm:PinHeader_1x02_P2.54mm_Vertical | TBD | pads/header | Pins: BAT+,BAT-. Do not connect to USB VBUS directly.
J17 | Reserved Spare Header | 2 | Connector_Generic:Conn_01x02 | Connector_PinHeader_2.54mm:PinHeader_1x02_P2.54mm_Vertical | 2.54mm | pin header | Optional spare/test header if wanted.
J18 | Power LED Ring | 2 | Connector_Generic:Conn_01x02 | Connector_JST:JST_SH_B2B-ZR_1x02_P1.00mm_Horizontal | 1.25mm or verify actual | JST/LED connector | LED+ from PCF P05, LED- to GND.
J19 | PCF Expansion A | 4 | Connector_Generic:Conn_01x04 | Connector_JST:JST_SH_B4B-ZR_1x04_P1.00mm_Horizontal | 1.25mm or verify actual | JST expansion | Pins: PCF P06,P07,P08,P09.
J20 | PCF Expansion B | 4 | Connector_Generic:Conn_01x04 | Connector_JST:JST_SH_B4B-ZR_1x04_P1.00mm_Horizontal | 1.25mm or verify actual | JST expansion | Pins: PCF P10,P11,P12,P13.
J21 | PCF Expansion C | 4 | Connector_Generic:Conn_01x04 | Connector_JST:JST_SH_B4B-ZR_1x04_P1.00mm_Horizontal | 1.25mm or verify actual | JST expansion | Pins: PCF P14,P15,P16,P17.
J22 | PCF8575 I2C Bus | 4 | Connector_Generic:Conn_01x04 | Connector_JST:JST_SH_B4B-ZR_1x04_P1.00mm_Horizontal | 1.25mm or verify actual | JST/module connector | Pins: 3V3_SW,GND,I2C_SCL,I2C_SDA for the PCF8575 module.
J23 | Aux Analog A2/A3 Header | 6 | Connector_Generic:Conn_01x06 | Connector_JST:JST_SH_B6B-ZR_1x06_P1.00mm_Horizontal | 1.25mm or verify actual | JST aux analog connector | Pins: GND,A2_B,3V3,GND,A3_B,3V3.
J24 | 3V3 I2C Power Switch Control/Input Side | 7 | Connector_Generic:Conn_01x07 | Connector_PinHeader_2.54mm:PinHeader_1x07_P2.54mm_Vertical | 2.54mm | Pololu/module header | One side of 3.3V switch module: VIN,VIN,GND,GND,ON,OFF,CTRL based on current schematic.
J25 | 5V ELRS Power Switch Control/Input Side | 7 | Connector_Generic:Conn_01x07 | Connector_PinHeader_2.54mm:PinHeader_1x07_P2.54mm_Vertical | 2.54mm | Pololu module header | One side of 5V switch module: VIN,VIN,GND,GND,ON,OFF,CTRL based on current schematic.
U1 | ADS1115 A Module | 10 | Connector_Generic:Conn_01x10 | Connector_PinHeader_2.54mm:PinHeader_1x10_P2.54mm_Vertical | 2.54mm | module header | Primary gimbal ADC: VCC,GND,SCL,SDA,ADDR,ALRT,A0,A1,A2,A3.
U2 | ADS1115 B Module | 10 | Connector_Generic:Conn_01x10 | Connector_PinHeader_2.54mm:PinHeader_1x10_P2.54mm_Vertical | 2.54mm | module header | Future aux ADC. Must set ADDR to non-0x48.
U3 | PCF8575 Module Side A | 11 | Connector_Generic:Conn_01x11 | Connector_PinHeader_2.54mm:PinHeader_1x11_P2.54mm_Vertical | 2.54mm | module side header | One side of PCF8575 module: 3V3_SW,GND,P00-P08.
U4 | PCF8575 Module Side B | 11 | Connector_Generic:Conn_01x11 | Connector_PinHeader_2.54mm:PinHeader_1x11_P2.54mm_Vertical | 2.54mm | module side header | Other side of PCF8575 module: 3V3_SW,GND,P17-P09 or physical order as installed.
TP1 | 5V Test Pad | 1 | Connector_Generic:Conn_01x01 | TestPoint:TestPoint_Pad_D1.5mm | NA | test pad | Probe Hosyond 5V rail.
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

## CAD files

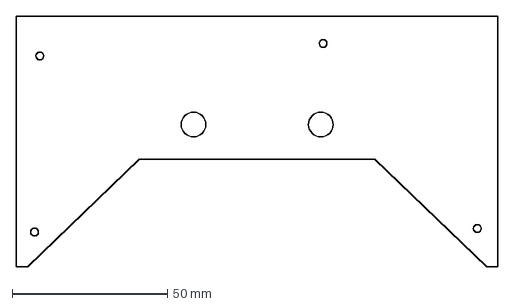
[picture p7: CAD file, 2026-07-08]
Daughterboard/fabrication/jlcpcb_2026-07-14_r16/source/daughterboard2.dxf
155.0 x 80.6 mm

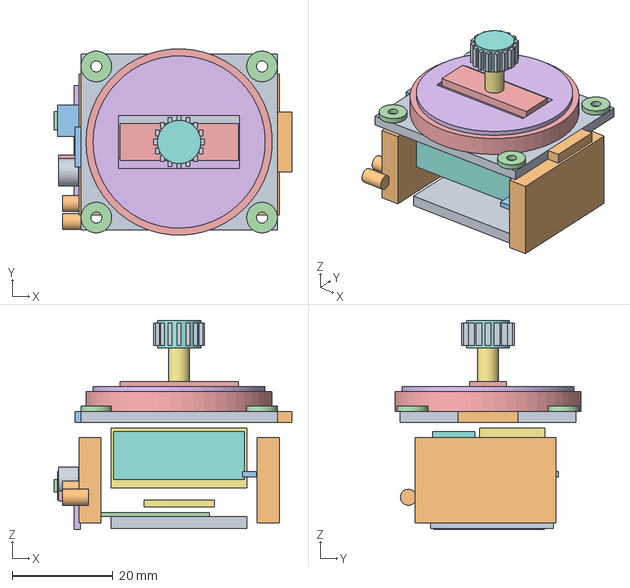
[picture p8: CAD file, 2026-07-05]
Daughterboard/radiomaster_x5_gimbal_fit_model.step
47.2 x 37.0 x 41.5 mm

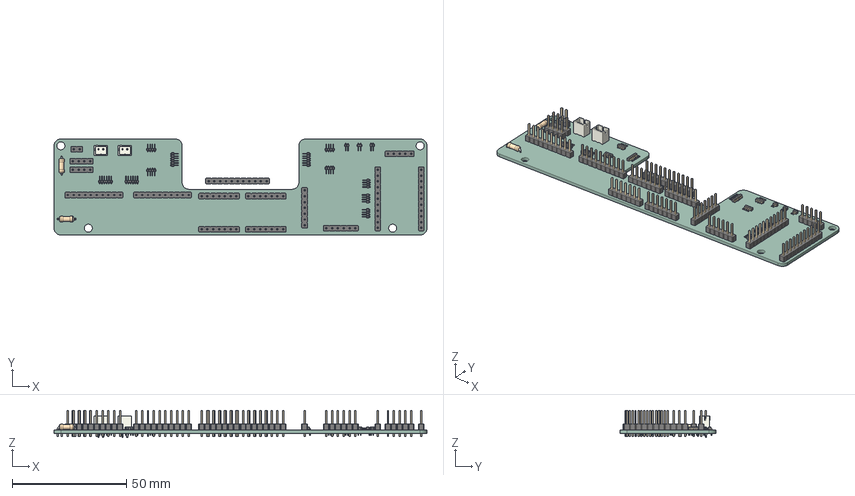
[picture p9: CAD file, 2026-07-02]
Hosyond_apr24b/Daughterboard/.step
163.0 x 42.0 x 11.9 mm
PinHeader_1x05_P254mm_Vertical
PinHeader_1x04_P254mm_Vertical x 2
PinHeader_1x04_P100mm_Horizontal x 7
PinHeader_1x10_P254mm_Vertical x 2
JST_B2B_PH_K x 2
PinHeader_1x06_P100mm_Horizontal x 4
R_Axial_DIN0207_L63mm_D25mm_P762mm_Horizontal x 2
PinHeader_1x07_P254mm_Vertical x 5
PinHeader_1x02_P100mm_Horizontal x 3
PinHeader_1x11_P254mm_Vertical x 3
PinHeader_1x02_P254mm_Vertical
PinHeader_1x06_P254mm_Vertical
daughterboard_PCB

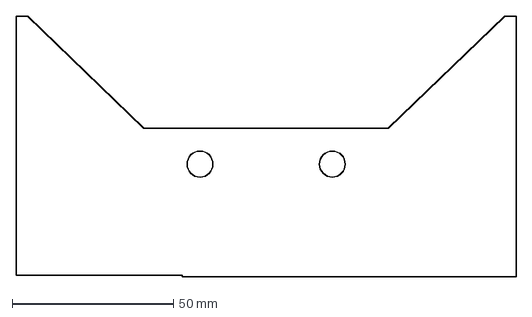
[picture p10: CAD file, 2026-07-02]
Hosyond_apr24b/Daughterboard/daughterboard2.dxf
155.0 x 80.6 mm

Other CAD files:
Daughterboard/radiomaster_x5_gimbal_fit_model.scad
Daughterboard/radiomaster_x5_gimbal_fit_model.stl

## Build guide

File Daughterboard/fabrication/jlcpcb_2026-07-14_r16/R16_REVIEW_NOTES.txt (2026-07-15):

ANUBIS DAUGHTERBOARD R16 FABRICATION REVIEW
Generated: 2026-07-14

RELEASE STATUS
- PCB DRC: 0 errors and 0 unconnected items.
- Schematic ERC: 0 violations.
- Schematic-to-PCB parity: no reported mismatches.
- Remaining PCB DRC items are non-blocking silkscreen/text warnings only:
  17 silkscreen-over-copper, 13 text-height, and 8 silkscreen-overlap warnings.

R16 HARDWARE
- Four copper layers: F.Cu, In1.Cu, In2.Cu, and B.Cu.
- BATT_RAW_P J7.3-to-F4.2 route is 1.0 mm throughout with 1.0/0.5 mm power vias.
- BATT_RAW_P F3.2-to-F4.2 route is 1.0 mm throughout.
- FET_BATT_P and FET_SRC_COMMON routes are 1.0 mm throughout with 1.0/0.5 mm vias.
- The narrow BATT_RAW_P branches are limited to voltage-sense and test-point connections.
- USB-C ground pins and shield are on GND.
- Charger BAT/SNS pins connect to protected BAT_SYS.
- R46 is series-connected between BATT_RAW_N and GND.
- Q1/Q2 use the CSD18502Q5B common-source high-side protection topology.
- BQ28Z610 SRP/SRN polarity matches the intended current-sense convention.

R16 JLCPCB FOOTPRINT/PART UPDATES
- L1: CKST0402-4.7uH/M, C3002596, matched to the current R16 footprint.
- L2: MDA4020-4R7M, C2847471, matched to the current R16 footprint.
- U2: BQ28Z610DRZR-R1, C2876556, TI DRZ 12-pin SON footprint.
- Q1/Q2: CSD18502Q5B, C473915, TI DNK/VSON-CLIP footprint.
- R49/R50 remain existing 10M gate-source bleed resistors. The assembly BOM maps
  them to 0603WAF1005T5E, JLCPCB C7250. No PCB component was added or moved.
- J5 remains the existing straight 1x4 2.54mm through-hole header and maps to
  X6511WV-04H-C60D30, JLCPCB C706876.
- J6 remains the existing straight 1x2 2.54mm through-hole header and maps to
  P6E02A-002550-B1P, JLCPCB C49375797.
- C8 remains the existing optional CBSET filter footprint and is marked DNP on
  the PCB. It is intentionally excluded from both the JLC assembly BOM and CPL.

UPLOAD FILES
- Upload Daughterboard_jlcpcb_gerber_drill.zip for PCB fabrication.
- Upload assembly/Daughterboard_jlcpcb_bom_template_filled.csv as the assembly BOM.
- Upload assembly/Daughterboard_jlcpcb_cpl.csv as the component placement file.

FINAL ORDER-SCREEN CHECK
- Confirm a four-layer stackup is selected.
- Confirm JLC recognizes both plated and non-plated drill files if separate files are shown.
- Review orientation markers for U1, U2, Q1, Q2, D4-D7, and all polarized connectors.
- Confirm every intended assembly BOM line is matched before payment.

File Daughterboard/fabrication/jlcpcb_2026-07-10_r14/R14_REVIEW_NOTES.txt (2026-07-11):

R14 fabrication package - 2026-07-10
Review notes updated - 2026-07-11

Major R14 changes:
- Q1 and Q2 changed to TI CSD18502Q5B using project-local DNK/VSON-CLIP footprint.
- Q1/Q2 JLC/LCSC part number is C473915.
- PCB was rerouted after the Q1/Q2 footprint swap.
- GND copper zone was refilled before DRC and Gerber export.

Stock-availability substitutions:
- R9 and R12 use RMC0603100K1%N, 100k 1% 0603, JLC/LCSC C269699.
  This replaces TD03H1003BT / C2961368 because of the available-stock shortfall.
- R42, R43, and R44 use RCT0310KFLF, 10k 1% 0603, JLC/LCSC C177644.
  This replaces 0603WAF1002T5E / C25804 because of the available-stock shortfall.
- Both substitutions retain the original resistance, tolerance, and 0603 footprint, so no PCB placement or routing change was required.
- The replacement LCSC numbers are present in the R14 JLCPCB BOM CSV/XLSX and part-audit files.

Checks:
- ERC: 0 errors, 0 warnings.
- R14 power topology audit: PASS.
- DRC: 40 non-connectivity violations, 0 unconnected pads/items.

Known DRC items:
- 6 U1 clearance items around the BQ25887 footprint, approximately 0.200-0.225 mm vs the 0.250 mm configured rule.
- Remaining items are silkscreen/text height/overlap or silkscreen-over-copper warnings.

Assembly notes:
- Q1/Q2 are selected as CSD18502Q5B, JLC/LCSC C473915.
- R9/R12 are selected as C269699; R42/R43/R44 are selected as C177644.
- Missing-parts report still lists J5/J6 through-hole headers and R49/R50 10M gate-source bleed resistors.
- If J5/J6 are not being assembled by JLC, remove them from the assembly upload or mark them user-installed.

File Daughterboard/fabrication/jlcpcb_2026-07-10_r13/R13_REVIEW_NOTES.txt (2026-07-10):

Anubis daughterboard R13 review package
Generated: 2026-07-10

Primary change from R12:
- The BQ28Z610 protection section was rewired from the incorrect low-side FET arrangement to a high-side N-FET protection path.
- Q1 and Q2 are now CSD16412Q5A high-side protection FETs.
- Charger BAT/SNS and downstream regulators now use protected BAT_SYS.
- R46 is the series low-side current-sense resistor between BATT_RAW_N and GND.
- USB-C A12/B12/shield are on GND.

Validation summary:
- ERC: 0 violations.
- DRC: 38 violations, 0 unconnected items.
- Known copper DRC items are local U1 clearance deltas around 0.20 mm to 0.225 mm versus the configured 0.25 mm rule.
- Remaining non-copper items are silkscreen/text warnings.
- R13 power-topology audit: PASS.

Assembly notes:
- JLC BOM/CPL files are in the assembly folder.
- Gerber/drill upload zip is Daughterboard_jlcpcb_gerber_drill.zip.
- Four assembly rows still need JLC part confirmation before final assembly upload:
  - Q1, Q2: CSD16412Q5A high-side protection FETs.
  - R49, R50: 10M 0603 gate-source bleed resistors.
- See reports/Daughterboard_r13_missing_jlc_parts.csv.

Critical review focus:
- Confirm Q1/Q2 footprint and pin orientation against the selected JLC-available FET.
- Confirm U1, U2, JST connectors, USB-C, and D4-D7 orientations in the JLC assembly preview.
- Confirm JLC accepts the known U1 clearances or adjust the local routing/rules before ordering.

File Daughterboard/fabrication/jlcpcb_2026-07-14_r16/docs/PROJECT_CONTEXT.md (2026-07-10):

# Project Context - Hosyond ESP32-S3 Daughterboard

Last updated: 2026-07-10

## Project Goal

This project is a custom daughterboard/carrier PCB for a Hosyond 2.8 inch ESP32-S3 display/dev board. The daughterboard replaces loose wiring with a compact board that provides battery charging/protection, switched 5 V and 3.3 V rails, UART/I2C/GPIO breakouts, onboard analog/digital expanders, and connectors for radio-control hardware such as ELRS, gimbals, D-pad/buttons, and auxiliary inputs.

The daughterboard should be manufactured and assembled offsite by JLCPCB as completely as possible. The main exception is the Pololu mini pushbutton power switch modules, which are installed separately on raised headers. Most passive parts, ICs, and connectors should be SMD/JLC-available where practical. Through-hole/user-installed headers are acceptable where the design intentionally needs them.

## Workspaces

Current daughterboard hardware workspace:

```text
C:\Users\Avala\OneDrive\Desktop\Daughterboard
```

Previous/main controller firmware workspace:

```text
C:\Users\Avala\OneDrive\Desktop\sketch_may7a
```

The previous project is about the main Hosyond ESP32-S3 board, its firmware, UI, protocol behavior, and controller functionality. A current copy of the daughterboard folder has also been placed inside that project at:

```text
C:\Users\Avala\OneDrive\Desktop\sketch_may7a\Daughterboard
```

Older carrier-board planning docs from the previous project are under:

```text
C:\Users\Avala\OneDrive\Desktop\sketch_may7a\project_anubis\Daughterboard
```

Those older docs are useful historical context, but they describe an earlier module-carrier version using a protected 1S pack and PCF8575/ADS1115 modules. The current design has moved to a 2S battery architecture and more onboard components.

## Current Daughterboard State

Primary KiCad files:

```text
Daughterboard.kicad_pro
Daughterboard.kicad_sch
Daughterboard.kicad_pcb
Daughterboard.kicad_sym
Daughterboard.net
Daughterboard.pretty\
```

Important custom footprints:

```text
Daughterboard.pretty\BQ28Z610_DRZ0012A_12SON_2.5x4mm_P0.5mm.kicad_mod
Daughterboard.pretty\Pololu_2808_Raised_Header.kicad_mod
Daughterboard.pretty\SOIC-28W_7.5x17.9mm_P1.27mm_NoPads11_14.kicad_mod
Daughterboard.pretty\SOT-23-6_NoPad6.kicad_mod
```

Current routed fabrication package:

```text
fabrication\jlcpcb_2026-07-10_r13.zip
fabrication\jlcpcb_2026-07-10_r13\
```

R13 assembly files:

```text
fabrication\jlcpcb_2026-07-10_r13\assembly\Daughterboard_jlcpcb_bom_template_filled.csv
fabrication\jlcpcb_2026-07-10_r13\assembly\Daughterboard_jlcpcb_bom_template_filled.xlsx
fabrication\jlcpcb_2026-07-10_r13\assembly\Daughterboard_jlcpcb_cpl.csv
fabrication\jlcpcb_2026-07-10_r13\Daughterboard_jlcpcb_gerber_drill.zip
```

J5 and J6 are intentionally through-hole/user-installed headers and are excluded from the JLC SMT BOM/CPL unless JLC through-hole assembly is explicitly used.

R13 topology update:

- `Daughterboard.kicad_sch`, `Daughterboard.net`, and `Daughterboard_pcb_bom.csv` now describe the corrected high-side BQ28Z610 protection topology.
- `Daughterboard.kicad_pcb` has been updated for R13 with the old single Q1 low-side footprint replaced by Q1/Q2 `CSD16412Q5A`, and R49/R50/C32/C33/TP13 added.
- The PCB has been rerouted after the R13 topology change.
- Backup before the R13 PCB staging is `Daughterboard.pre_r13_topology_backup.kicad_pcb`.

R14 working update:

- R14 swaps Q1/Q2 from `CSD16412Q5A` to JLC-available TI `CSD18502Q5B`, JLC/LCSC `C473915`.
- The schematic now uses a real 1-8 pin `CSD18502Q5B` symbol: pins 1-3 source, pin 4 gate, pins 5-8 drain.
- The PCB now uses project-local footprint `Daughterboard:CSD18502Q5B_DNK0008A_VSON-CLIP_5x6mm` for Q1/Q2.
- Routed traces/vias were intentionally cleared for the Q1/Q2 footprint swap, then the board was rerouted for R14.
- Zones were refilled after the R14 reroute.
- R14 ERC is clean: 0 violations in `r14_post_route_erc.rpt`.
- R14 topology audit passes in `verify_r14_power_topology.py`.
- R14 DRC currently reports 40 non-connectivity violations and 0 unconnected pads/items in `r14_post_route_drc.rpt`.
- Backup before the R14 swap is `Daughterboard.pre_r14_csd18502_swap.kicad_pcb` and `Daughterboard.pre_r14_csd18502_swap.kicad_sch`.

## Power Architecture

The daughterboard is intended to run from installed batteries. The current design supports a 2S battery connection through a standard 2S LiPo balance lead, so users can use either a 2S LiPo pack or two 18650 cells configured as a 2S pack.

Original charging target:

- USB-C input: 5 V
- Charge current: 500 mA minimum target, 1.5 A maximum
- 5 V switched rail: about 1 A max
- 3.3 V switched rail: about 500 mA max

Current direction:

- 2S battery management/protection moved away from the unavailable `S-8252AAH-M6T1U`.
- `BQ28Z610DRZR-R1` was added as the major 2S battery gauge/protection/management IC.
- R13 rewired the BQ28Z610 protection topology from the old incompatible low-side FET path to a high-side N-FET path. R14 keeps that topology and uses two `CSD18502Q5B` FETs: `Q1` charge FET and `Q2` discharge FET.
- Raw cell-stack positive is now `BATT_RAW_P`; protected/system positive is `BAT_SYS`.
- `R46` is now documented as a true series current-sense resistor between raw cell negative `BATT_RAW_N` and protected/system `GND`.
- USB-C ground pins `A12`, `B12`, and shield are on `GND`; the old accidental `Q1_DRAIN_COMMON` net was removed from the generated schematic/netlist.
- USB-C VBUS and CC resistors are on the board. CC resistors were placed close to the USB-C port.
- B.Cu has a GND copper zone/ground plane.
- Power/high-current nets such as battery, charge, 5 V, switched 5 V, 3.3 V, and switched 3.3 V were assigned wider routing rules during layout.

Known firmware integration note:

- The firmware still has 1S battery voltage assumptions in places: empty/full around 3.30 V to 4.20 V and divider ratio 2.0.
- The hardware is now 2S. Firmware battery measurement, warnings, fuel-gauge integration, and any ADC divider expectations must be reviewed before relying on battery display/protection behavior.

## Switched Rails and Pololu Modules

The design incorporates two Pololu mini pushbutton power switch modules, Pololu product 2808:

- One switches the 5 V output rail.
- One switches the 3.3 V output rail.

The intent from the daughterboard design thread:

- `GPIO2` controls one Pololu switch.
- `GPIO3` controls the other Pololu switch.
- `GPIO14` and `GPIO21` route to the deep-sleep/wake pushbutton header `J6`.

Current firmware assignment:

- `GPIO2` drives the 5 V Pololu switch control path.
- `GPIO3` drives the 3.3 V Pololu switch control path.
- `GPIO14` is the deep-sleep/wake button sense pin.
- `GPIO21` is the deep-sleep/wake button reference pin.
- The old GPIO14/GPIO21 power LED behavior is disabled so it does not conflict with `J6`.

The UART-to-ELRS pinout remains similar to earlier notes: if the board pin order does not match a given ELRS module harness, it can be manually wired/crossed later.

## Signal and Connector Map

Hosyond ESP32-S3 board interface:

- I2C SDA: firmware currently uses GPIO16.
- I2C SCL: firmware currently uses GPIO15.
- ELRS/UART default pins: firmware uses TX GPIO44 and RX GPIO43, with auto/swap handling.
- Battery ADC: firmware currently uses GPIO9.

Primary daughterboard connector intent:

- UART from Hosyond TX/RX routes to a 5-pin 1.25 mm JST-GH top-entry connector with `+5V_SW` and GND.
- I2C SDA/SCL routes to a 4-pin 2.54 mm through-hole header `J5` with `+3V3_SW` and GND.
- `J6` is a 2-pin 2.54 mm through-hole header for a pushbutton/deep-sleep signal path.
- Gimbal connectors were split so each gimbal has two 3-wire JST connections: GND, analog input, and `+3V3_SW`.
- Remaining analog/GPIO breakout signals were moved to labeled test pads/solder pads where full connectors were not needed.

Connector notes:

- `J4` uses top-entry `BM05B-GHS-TBT(LF)(SN)(N)` style connector for the 5-pin JST-GH output.
- `J7` is the 2S balance connector, using a JST-XH style part such as `S3B-XH-A(LF)(SN)`.
- `J5` and `J6` were corrected to through-hole 2.54 mm headers and remain that way in the R13 fabrication outputs.

## Onboard I2C and Analog Devices

The board includes onboard components instead of relying on plug-in ADS1115/PCF modules:

- Two `ADS1115` ADC circuits for about 8 analog inputs.
- One `MCP23017` GPIO expander circuit.
- ADS1115s, MCP23017, attached analog devices, and other 3.3 V peripherals are powered from `+3V3_SW`, so powering down the switched 3.3 V rail shuts them off.
- ESD arrays D4-D7 were updated to use the JLC-selected SRV05-style SOT-23-6 part. The verified pinout is:
  - IO pins: 1, 3, 4, 6
  - GND: pin 2
  - `+3V3_SW_LOGIC`: pin 5

Firmware currently expects:

- Primary ADS1115 at I2C address `0x48` for stick axes.
- Auxiliary ADS1115 at I2C address `0x49` for spare analog inputs.
- MCP23017 fixed at I2C address `0x20`.
- MCP23017 active-low D-pad mapping on low GPIO bits:
  - select: bit 0
  - left: bit 1
  - up: bit 2
  - down: bit 3
  - right: bit 4

Firmware caution:

- If switched `+3V3_SW` removes power from the I2C devices while SDA/SCL remain connected, firmware and hardware should account for possible back-powering through I2C lines. ESD/protection and bus behavior should be checked.

## Main Firmware Context

Main sketch:

```text
C:\Users\Avala\OneDrive\Desktop\sketch_may7a\Hosyond_apr24b\Hosyond_apr24b.ino
```

The firmware is a large Hosyond ESP32-S3 transmitter/controller application. It includes:

- TFT/touch UI using `TFT_eSPI` and FT6336U touch.
- Model storage and settings.
- Stick calibration, expo/rates, trims, endpoints, failsafe, drive type, and mixing.
- Protocol selection between ELRS/CRSF and ESP-NOW.
- ELRS module support on `Serial1`, with default pins TX GPIO44 and RX GPIO43, auto/swap logic, and 5,250,000 baud CRSF handling.
- ESP-NOW transmitter support and receiver/bind handling.
- Dual ADS1115 support for the daughterboard ADCs at `0x48` and `0x49`.
- MCP23017 GPIO expander support at `0x20`.
- Battery display, warnings, and auto deep-sleep behavior.
- Display backlight and audio support.

Important current firmware defines:

```text
POWER_BUTTON_SENSE_PIN 14
POWER_BUTTON_REF_PIN   21
POWER_LED_ENABLED      false
UART_5V_ENABLE_PIN     2
I2C_3V3_ENABLE_PIN     3
BATTERY_ADC_PIN        9
I2C_SDA_PIN            16
I2C_SCL_PIN            15
ADS1115 primary/aux    0x48 / 0x49
MCP23017 address       0x20
ELRS default TX/RX     44/43
```

There is also an ESP-NOW receiver sketch in:

```text
C:\Users\Avala\OneDrive\Desktop\sketch_may7a\ESPNow_S3_Receiver
```

## Mechanical Context

The current daughterboard outline is based on:

```text
daughterboard2.dxf
Daughterboardv2.step
```

The board is a wide, notched shape that fits around/under the Hosyond board. The Hosyond board sits above the daughterboard on standoffs, roughly 20 mm above the daughterboard. The upper gap/center area receives the Hosyond board. The USB-C connector is intended to sit in the center island/strip between the two halves.

Placement intent from layout work:

- UART near the left side of the Hosyond gap.
- GPIO and I2C near the right side of the Hosyond gap.
- UART output near the lower center strip.
- Power management/protection mostly on the left side.
- I2C circuits and analog/GPIO expansion mostly on the right side.
- Gimbal connectors near the gimbal wire exits.

RadioMaster Pocket/Zorro X5 gimbal reference work:

- Center circle where the stick emerges: about 37 mm diameter.
- Mounting hole spacing: about 32.9 mm by 30 mm center-to-center.
- Mounting plate: about 39 mm wide, 41 mm at the bump, by 35 mm tall.
- Bottom of gimbal to top of stick: about 43 mm.
- Reference images and generated fit models are retained in the workspace.

## Fabrication and Checks

R13 fabrication outputs were generated after:

- Converting the PCB to 4 layers.
- Updating J5/J6 to through-hole 2.54 mm headers.
- Updating D4-D7 to the normal 6-pad SOT-23-6 ESD footprint.
- Reworking the `BQ28Z610` protection circuit into the corrected high-side FET topology.
- Rebuilding Gerbers, drill files, JLC BOM/CPL files, validation reports, and `fabrication\jlcpcb_2026-07-10_r13.zip`.

Latest known checks from R13:

- ERC: 0 errors, 0 warnings.
- DRC: 38 reported violations.
- Unconnected pads/items: 0 reported in the final checked state before packaging.
- R13 topology audit: PASS.
- The remaining DRC items are accepted/known items:
  - U1 clearance differences, roughly 0.20 mm to 0.225 mm versus a 0.25 mm rule.
  - Silkscreen/text-size/overlap warnings that should not normally block fabrication.
- In the active R14 working files, Q1/Q2 are selected as `CSD18502Q5B`, JLC/LCSC `C473915`.
- JLC assembly still needs confirmed selections for `R49` and `R50`, the 10M 0603 gate-source bleed resistors.

Manufacturing caution:

- Before ordering, re-run KiCad DRC/ERC after any manual edits, refill zones, and regenerate fabrication files.
- Silkscreen issues are usually non-critical, but copper clearance, drill, board outline, missing nets, and footprint orientation issues should be treated as critical.
- Check JLC part availability again before final ordering, because stock and part lifecycle status can change.

## BOM and Part Selection Notes

Current major JLC/assembly direction:

- Use JLC-available SMD components wherever possible.
- Keep 1.25 mm/2.54 mm JST or pin headers as chosen unless there is a specific layout/manufacturing reason to change.
- Non-component items such as test pads and solder pads should be placed at the bottom of any human-facing BOM or excluded from assembly upload.

Notable parts/substitutions from the design thread:

- `BQ28Z610DRZR-R1` replaced the unavailable/minimum-order-problem `S-8252AAH-M6T1U` direction.
- R13 replaced the old `CSD83325L`/`PT8810` low-side FET position with two high-side protection FETs. R14 changed those FETs to `CSD18502Q5B` so JLCPCB can assemble Q1/Q2 using an in-stock part.
- `C2012X5R1C226M125AC` substituted for `GRM21BR61C226ME44L`.
- `BM05B-GHS-TBT(LF)(SN)(N)` selected for the top-entry 5-pin JST-GH connector.
- `S3B-XH-A(LF)(SN)` style part used for the 2S balance connector.
- `BSMD1206-200-16V` used for F1-F4 in the JLC audit.

Useful BOM files:

```text
Daughterboard_pcb_bom.csv
Daughterboard_current_jlc_part_audit.csv
fabrication\jlcpcb_2026-07-10_r13\assembly\Daughterboard_jlcpcb_bom_template_filled.csv
fabrication\jlcpcb_2026-07-10_r13\assembly\Daughterboard_jlcpcb_cpl.csv
```

## Open Integration Items

1. Update firmware for the 2S battery system:
   - ADC divider/scaling.
   - Battery full/empty/warning thresholds.
   - Whether to read `BQ28Z610` over I2C/SMBus or keep separate analog battery sensing.

2. Confirm daughterboard I2C behavior on first hardware:
   - Primary ADS1115 at `0x48` feeds the four stick axes.
   - Auxiliary ADS1115 at `0x49` feeds spare analog inputs, with AIN4/AIN5 mapped into CH5/CH6.
   - MCP23017 at `0x20` replaces the old PCF8575-style GPIO path.

3. Confirm JLC orientation before ordering:
   - Especially U1/BQ25887, U2/BQ28Z610, Q1/Q2/CSD18502Q5B, USB-C, JST connectors, and ESD arrays.
   - KiCad pin 1 marker orientation and JLC preview orientation can look different depending on rotation convention, so use pad numbering and datasheets, not only the visual corner.

4. Re-run DRC/ERC and regenerate fabrication files after every footprint, placement, routing, or BOM-impacting change.

## Useful Reference Files

Daughterboard hardware:

```text
power_board_design.md
S8252_E.pdf
SRV05-4-TCT_C13612_actual.pdf
SRV05-4-TCT_C13612_datasheet.pdf
JLCPCB_BOM_Template.xls
update_jlc_footprint_migration.ps1
```

Mechanical/gimbal:

```text
daughterboard2.dxf
Daughterboardv2.step
radiomaster_x5_gimbal_fit_model.step
radiomaster_x5_gimbal_fit_model.stl
fusion360_x5_gimbal_model.py
x5Front.webp
x5Side1.webp
x5Side2.webp
x5Side3.jpg
x5Bottom.webp
x5dimensions.webp
```

Older previous-project context:

```text
C:\Users\Avala\OneDrive\Desktop\sketch_may7a\project_anubis\Daughterboard\Hosyond_carrier_block_diagram.md
C:\Users\Avala\OneDrive\Desktop\sketch_may7a\project_anubis\Daughterboard\Hosyond_carrier_connector_inventory.csv
C:\Users\Avala\OneDrive\Desktop\sketch_may7a\project_anubis\Daughterboard\Hosyond_carrier_net_table.csv
C:\Users\Avala\OneDrive\Desktop\sketch_may7a\project_anubis\Daughterboard\Hosyond_carrier_mechanical_constraints.md
```

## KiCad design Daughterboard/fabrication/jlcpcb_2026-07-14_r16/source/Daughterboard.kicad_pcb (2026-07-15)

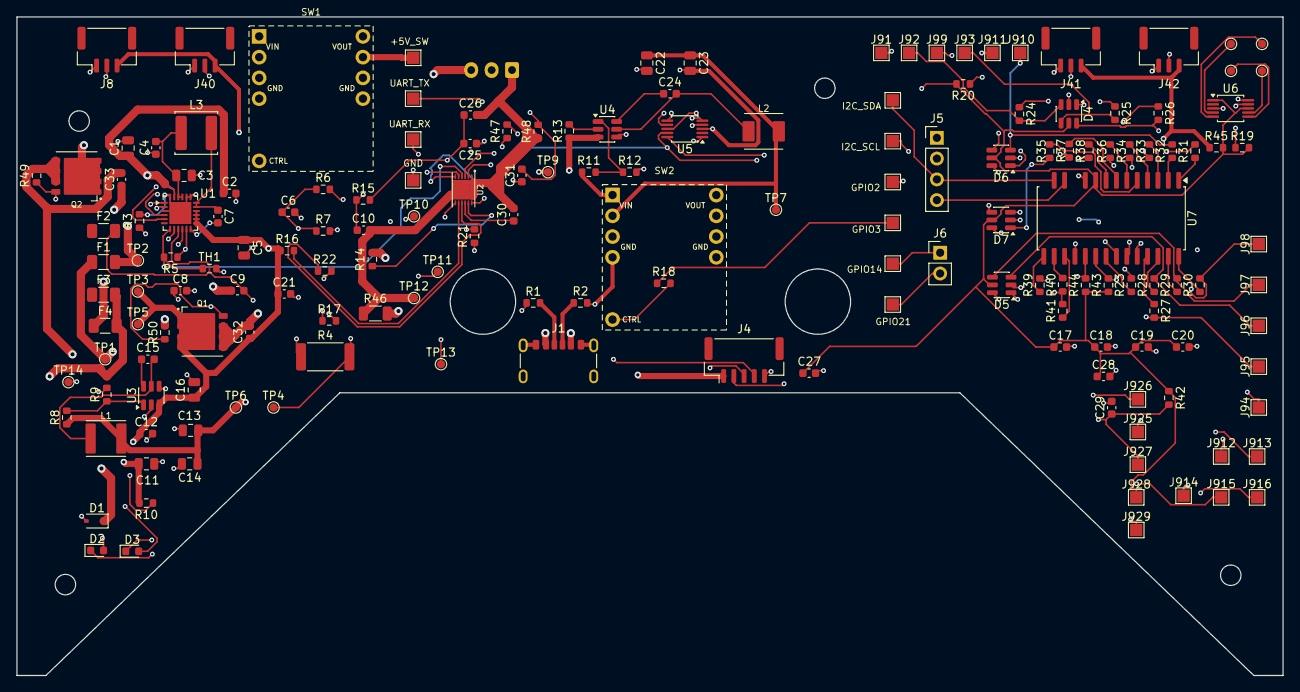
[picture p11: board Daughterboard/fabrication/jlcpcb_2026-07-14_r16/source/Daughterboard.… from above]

Board: 4 copper layers, 155.0 x 80.6 mm, 166 parts (0 on the bottom side), 101 nets.

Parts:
C1: 10uF 10V X5R; C_0805_2012Metric
C2, C17, C19, C27, C29: 100nF 10V X7R; C_0603_1608Metric
C3, C5, C13, C14, C22, C23: 22uF 16V X5R; C_0805_2012Metric
C4, C7, C9, C10, C12, C15, C21, C24, C25, C26, C31: 100nF 16V X7R; C_0603_1608Metric
C6: 4.7uF 6.3V X5R; C_0603_1608Metric
C8: 100nF 10V X7R DNP; C_0603_1608Metric
C11, C16: 10uF 16V X5R; C_0805_2012Metric
C18, C20, C28: 1uF 10V X5R; C_0603_1608Metric
C30: 2.2uF 10V X5R; C_0603_1608Metric
C32, C33: 100nF 25V X7R; C_0603_1608Metric
D1: PESD5V0S1BA 5V VBUS TVS; D_SOD-323
D2: LED green; LED_0603_1608Metric
D3: LED blue; LED_0603_1608Metric
D4, D5, D6, D7: SRV05-4.TCT / C13612 4ch ESD; SOT-23-6
F1: BSMD1206-200-16V 2A hold polyfuse; Fuse_1206_3216Metric
F2: BSMD1206-200-16V cell1 PTC; Fuse_1206_3216Metric
F3: BSMD1206-200-16V cell2 PTC; Fuse_1206_3216Metric
F4: BSMD1206-200-16V system fuse; Fuse_1206_3216Metric
J1: USB-C 5V Sink; USB_C_Receptacle_GCT_USB4125-xx-x_6P_TopMnt_Horizontal
J4: BM05B-GHS-TBT UART JST-GH top-entry 1.25mm; JST_GH_BM05B-GHS-TBT_1x05-1MP_P1.25mm_Vertical
J5: I2C 2.54mm through-hole male header; PinHeader_1x04_P2.54mm_Vertical
J6: Deep sleep 2.54mm through-hole header; PinHeader_1x02_P2.54mm_Vertical
J7: 2S balance input JST-XH side-entry; JST_XH_S3B-XH-A_1x03_P2.50mm_Horizontal
J8: Left gimbal A JST-GH 1.25mm; JST_GH_BM03B-GHS-TBT_1x03-1MP_P1.25mm_Vertical
J30: J3P Hosyond +5V_SW solder pad; TestPoint_Pad_1.5x1.5mm
J31: J3A Hosyond UART_TX solder pad; TestPoint_Pad_1.5x1.5mm
J32: J3B Hosyond UART_RX solder pad; TestPoint_Pad_1.5x1.5mm
J33: J3C Hosyond I2C_SDA solder pad; TestPoint_Pad_1.5x1.5mm
J34: J3D Hosyond I2C_SCL solder pad; TestPoint_Pad_1.5x1.5mm
J35: J3E Hosyond GPIO2 solder pad; TestPoint_Pad_1.5x1.5mm
J36: J3F Hosyond GPIO3 solder pad; TestPoint_Pad_1.5x1.5mm
J37: J3G Hosyond GPIO14 solder pad; TestPoint_Pad_1.5x1.5mm
J38: J3H Hosyond GPIO21 solder pad; TestPoint_Pad_1.5x1.5mm
J39: J3I Hosyond GND solder pad; TestPoint_Pad_1.5x1.5mm
J40: Left gimbal B JST-GH 1.25mm; JST_GH_BM03B-GHS-TBT_1x03-1MP_P1.25mm_Vertical
J41: Right gimbal A JST-GH 1.25mm; JST_GH_BM03B-GHS-TBT_1x03-1MP_P1.25mm_Vertical
J42: Right gimbal B JST-GH 1.25mm; JST_GH_BM03B-GHS-TBT_1x03-1MP_P1.25mm_Vertical
J91: MCP23017 GPA0 solder pad; TestPoint_Pad_1.5x1.5mm
J92: MCP23017 GPA1 solder pad; TestPoint_Pad_1.5x1.5mm
J93: MCP23017 GPA2 solder pad; TestPoint_Pad_1.5x1.5mm
J94: MCP23017 GPA3 solder pad; TestPoint_Pad_1.5x1.5mm
J95: MCP23017 GPA4 solder pad; TestPoint_Pad_1.5x1.5mm
J96: MCP23017 GPA5 solder pad; TestPoint_Pad_1.5x1.5mm
J97: MCP23017 GPA6 solder pad; TestPoint_Pad_1.5x1.5mm
J98: MCP23017 GPA7 solder pad; TestPoint_Pad_1.5x1.5mm
J99: MCP23017 GPB0 solder pad; TestPoint_Pad_1.5x1.5mm
J910: MCP23017 GPB1 solder pad; TestPoint_Pad_1.5x1.5mm
J911: MCP23017 GPB2 solder pad; TestPoint_Pad_1.5x1.5mm
J912: MCP23017 GPB3 solder pad; TestPoint_Pad_1.5x1.5mm
J913: MCP23017 GPB4 solder pad; TestPoint_Pad_1.5x1.5mm
J914: MCP23017 GPB5 solder pad; TestPoint_Pad_1.5x1.5mm
J915: MCP23017 GPB6 solder pad; TestPoint_Pad_1.5x1.5mm
J916: MCP23017 GPB7 solder pad; TestPoint_Pad_1.5x1.5mm
J925: MCP23017 INTA solder pad; TestPoint_Pad_1.5x1.5mm
J926: MCP23017 INTB solder pad; TestPoint_Pad_1.5x1.5mm
J927: MCP23017 RESET solder pad; TestPoint_Pad_1.5x1.5mm
J928: MCP23017 +3V3_SW solder pad; TestPoint_Pad_1.5x1.5mm
J929: MCP23017 GND solder pad; TestPoint_Pad_1.5x1.5mm
L1: 4.7uH >=3A sat; CENKER_CKST0402_4.6x4.1mm
L2: 4.7uH >=2A sat; KOHERelec_MDA4020_4.45x4.1mm
L3: ANR5040T1R0M 1uH; L_APV_ANR5040
Q1: CSD18502Q5B charge FET; CSD18502Q5B_DNK0008A_VSON-CLIP_5x6mm
Q2: CSD18502Q5B discharge FET; CSD18502Q5B_DNK0008A_VSON-CLIP_5x6mm
R1, R2: 5.1k 1%; R_0603_1608Metric
R3: 806R 1% ILIM; R_0603_1608Metric
R4: 43R 1W CBSET; R_2512_6332Metric
R5: 10k 1%; R_0603_1608Metric
R6, R7: 2.2k; R_0603_1608Metric
R8: 523k 1%; R_0603_1608Metric
R9, R12: 100k 1%; R_0603_1608Metric
R10, R13: 100k; R_0603_1608Metric
R11: 316k 1%; R_0603_1608Metric
R14, R15: 470R 1%; R_0603_1608Metric
R16, R21, R22, R23, R24, R25, R26, R27, R28, R29, R30, R31, R32, R33, R34, R35, R36, R37, R38, R47, R48: 100R; R_0603_1608Metric
R17, R18: 330R; R_0603_1608Metric
R19, R20: 4.7k; R_0603_1608Metric
R39, R40, R41, R45: 0R; R_0603_1608Metric
R42, R43, R44: 10k; R_0603_1608Metric
R46: 2mR 1% 50ppm; R_1206_3216Metric
R49, R50: 10M; R_0603_1608Metric
SW1: Pololu #2808 5V switch; Pololu_2808_Raised_Header
SW2: Pololu #2808 3V3 switch; Pololu_2808_Raised_Header
TH1: NCP18XH103F03RB 10k NTC; R_0603_1608Metric
TP1: USB_VBUS test pad; TestPoint_Pad_D1.0mm
TP2: CHG_IN test pad; TestPoint_Pad_D1.0mm
TP3, TP5: BAT_SYS test pad; TestPoint_Pad_D1.0mm
TP4: CELL_MID test pad; TestPoint_Pad_D1.0mm
TP6: +5V test pad; TestPoint_Pad_D1.0mm
TP7: +3V3 test pad; TestPoint_Pad_D1.0mm
TP9: +3V3_SW test pad; TestPoint_Pad_D1.0mm
TP10: CHG_STAT test pad; TestPoint_Pad_D1.0mm
TP11: PG_STAT test pad; TestPoint_Pad_D1.0mm
TP12: BATT_RAW_N test pad; TestPoint_Pad_D1.0mm
TP13: BATT_RAW_P test pad; TestPoint_Pad_D1.0mm
TP14: GND test pad; TestPoint_Pad_D1.0mm
TP15: AIN4 test pad; TestPoint_Pad_D1.0mm
TP16: AIN5 test pad; TestPoint_Pad_D1.0mm
TP17: AIN6 test pad; TestPoint_Pad_D1.0mm
TP18: AIN7 test pad; TestPoint_Pad_D1.0mm
U1: BQ25887RGER 2S charger; Texas_RGE0024H_VQFN-24-1EP_4x4mm_P0.5mm_EP2.7x2.7mm
U2: BQ28Z610DRZR-R1; TI_DRZ0012A_VSON-12_4x2.5mm_P0.4mm
U3: AP63200WU-7 5V Buck; TSOT-23-6
U4: AP63200WU-7 3V3 Buck; TSOT-23-6
U5: ADS1115IDGSR 0x48; TSSOP-10_3x3mm_P0.5mm
U6: ADS1115IDGSR 0x49; TSSOP-10_3x3mm_P0.5mm
U7: MCP23017-E/SO; SOIC-28W_7.5x17.9mm_P1.27mm_NoPads11_14

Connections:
+3V3: C22.1, C23.1, L2.2, R11.1, SW2.1, TP7.1
+3V3_SW: J5.1, J8.3, J40.3, J41.3, J42.3, R45.1, SW2.2, TP9.1
+3V3_SW_LOGIC: C17.1, C18.1, C19.1, C20.1, C27.1, C28.1, D4.5, D5.5, D6.5, D7.5, J928.1, R19.2, R20.2, R42.1, R43.1, R44.1, R45.2, U5.8, U6.1, U6.8, U7.9
+5V: C13.1, C14.1, L1.2, R8.1, SW1.1, TP6.1
+5V_SW: J4.1, J30.1, SW1.2
AIN0: J8.2, U5.4
AIN1: J40.2, U5.5
AIN2: J41.2, U5.6
AIN3: J42.2, U5.7
AIN4: TP15.1, U6.4
AIN5: TP16.1, U6.5
AIN6: TP17.1, U6.6
AIN7: TP18.1, U6.7
BATT_RAW_N: C10.2, C26.2, C30.2, J7.1, R46.1, R48.1, TP12.1, U2.1, U2.13
BATT_RAW_P: C9.1, F3.2, F4.2, J7.3, R14.1, TP13.1
BAT_SYS: C5.1, C11.1, C12.1, C16.1, C21.1, C32.1, Q1.5, Q1.6, Q1.7, Q1.8, R10.2, R13.2, R16.1, TP3.1, TP5.1, U1.13, U1.14, U1.15, U1.16, U3.3, U4.3
BQ_CHG: R22.1, U2.9
BQ_DSG: R21.1, U2.7
BQ_PACK: R16.2, U2.8
BQ_PBI: C30.1, U2.10
BQ_SRN: C31.1, R47.2, U2.2
BQ_SRP: C31.2, R48.2, U2.3
BST_3V3: C24.1, U4.6
BST_5V: C15.1, U3.6
BTST: C7.1, U1.12
CBSET: C8.1, R4.1, U1.10
CC1: J1.A5, R1.1
CC2: J1.B5, R2.1
CELL_MID: C9.2, C10.1, F2.2, J7.2, R4.2, R15.1, TP4.1, U1.9
CHG_IN: C1.1, C2.1, D1.1, F1.2, TP2.1, U1.23
CHG_STAT: D2.2, TP10.1, U1.2
CHG_SW: C7.2, L3.2, U1.17, U1.18
CO_GATE: Q1.4, R22.2, R50.1
CTRL_3V3_SW: R18.2, SW2.4
CTRL_5V_SW: R17.2, SW1.4
DO_GATE: Q2.4, R21.2, R49.1
EN_3V3: R13.1, U4.2
EN_5V: R10.1, U3.2
EXP_GPA0: D4.1, J91.1, R23.2
EXP_GPA1: D4.3, J92.1, R24.2
EXP_GPA2: D4.4, J93.1, R25.2
EXP_GPA3: D4.6, J94.1, R26.2
EXP_GPA4: D5.1, J95.1, R27.2
EXP_GPA5: D5.3, J96.1, R28.2
EXP_GPA6: D5.4, J97.1, R29.2
EXP_GPA7: D5.6, J98.1, R30.2
EXP_GPB0: D6.1, J99.1, R31.2
EXP_GPB1: D6.3, J910.1, R32.2
EXP_GPB2: D6.4, J911.1, R33.2
EXP_GPB3: D6.6, J912.1, R34.2
EXP_GPB4: D7.1, J913.1, R35.2
EXP_GPB5: D7.3, J914.1, R36.2
EXP_GPB6: D7.4, J915.1, R37.2
EXP_GPB7: D7.6, J916.1, R38.2
FB_3V3: R11.2, R12.1, U4.1
FB_5V: R8.2, R9.1, U3.1
FET_BATT_P: C33.1, F4.1, Q2.5, Q2.6, Q2.7, Q2.8
FET_SRC_COMMON: C32.2, C33.2, Q1.1, Q1.2, Q1.3, Q2.1, Q2.2, Q2.3, R49.2, R50.2
GND: C1.2, C2.2, C3.2, C4.2, C5.2, C6.2, C8.2, C11.2, C12.2, C13.2, C14.2, C16.2, C17.2, C18.2, C19.2, C20.2, C21.2, C22.2, C23.2, C27.2, C28.2, C29.2, D1.2, D4.2, D5.2, D6.2, D7.2, J1.A12, J1.B12, J1.SH, J4.2, J4.5, J5.2, J8.1, J39.1, J40.1, J41.1, J42.1, J929.1, R1.2, R2.2, R3.2, R9.2, R12.2, R39.2, R40.2, R41.2, R46.2, R47.1, SW1.3, SW2.3, TH1.2, TP14.1, U1.3, U1.19, U1.20, U1.24, U1.25, U3.4, U4.4, U5.1, U5.3, U6.3, U7.10
GPIO2: J35.1, R17.1
GPIO3: J36.1, R18.1
GPIO14: J6.1, J37.1
GPIO21: J6.2, J38.1
I2C_SCL: J5.4, J34.1, R20.1, U1.5, U2.5, U5.10, U6.10, U7.12
I2C_SDA: J5.3, J33.1, R19.1, U1.4, U2.6, U5.9, U6.9, U7.13
ILIM: R3.1, U1.8
LED_CHG_A: D2.1, R6.2
LED_PGOOD_A: D3.1, R7.2
MCP_A0: R39.1, U7.15
MCP_A1: R40.1, U7.16
MCP_A2: R41.1, U7.17
MCP_GPA0: R23.1, U7.21
MCP_GPA1: R24.1, U7.22
MCP_GPA2: R25.1, U7.23
MCP_GPA3: R26.1, U7.24
MCP_GPA4: R27.1, U7.25
MCP_GPA5: R28.1, U7.26
MCP_GPA6: R29.1, U7.27
MCP_GPA7: R30.1, U7.28
MCP_GPB0: R31.1, U7.1
MCP_GPB1: R32.1, U7.2
MCP_GPB2: R33.1, U7.3
MCP_GPB3: R34.1, U7.4
MCP_GPB4: R35.1, U7.5
MCP_GPB5: R36.1, U7.6
MCP_GPB6: R37.1, U7.7
MCP_GPB7: R38.1, U7.8
MCP_INTA: J925.1, R43.2, U7.20
MCP_INTB: J926.1, R44.2, U7.19
MCP_RESET: C29.1, J927.1, R42.2, U7.18
PG_STAT: D3.2, TP11.1, U1.1
PMID: C3.1, C4.1, L3.1, U1.21, U1.22
PROT_VC: C25.2, C26.1, R15.2, U2.12
PROT_VDD: C25.1, R14.2, U2.11
REGN: C6.1, R5.1, R6.1, R7.1, U1.11
SW_3V3: C24.2, L2.1, U4.5
SW_5V: C15.2, L1.1, U3.5
TS: R5.2, TH1.1, U1.7, U2.4
UART_RX: J4.4, J32.1
UART_TX: J4.3, J31.1
USB_VBUS: F1.1, J1.A9, J1.B9, TP1.1

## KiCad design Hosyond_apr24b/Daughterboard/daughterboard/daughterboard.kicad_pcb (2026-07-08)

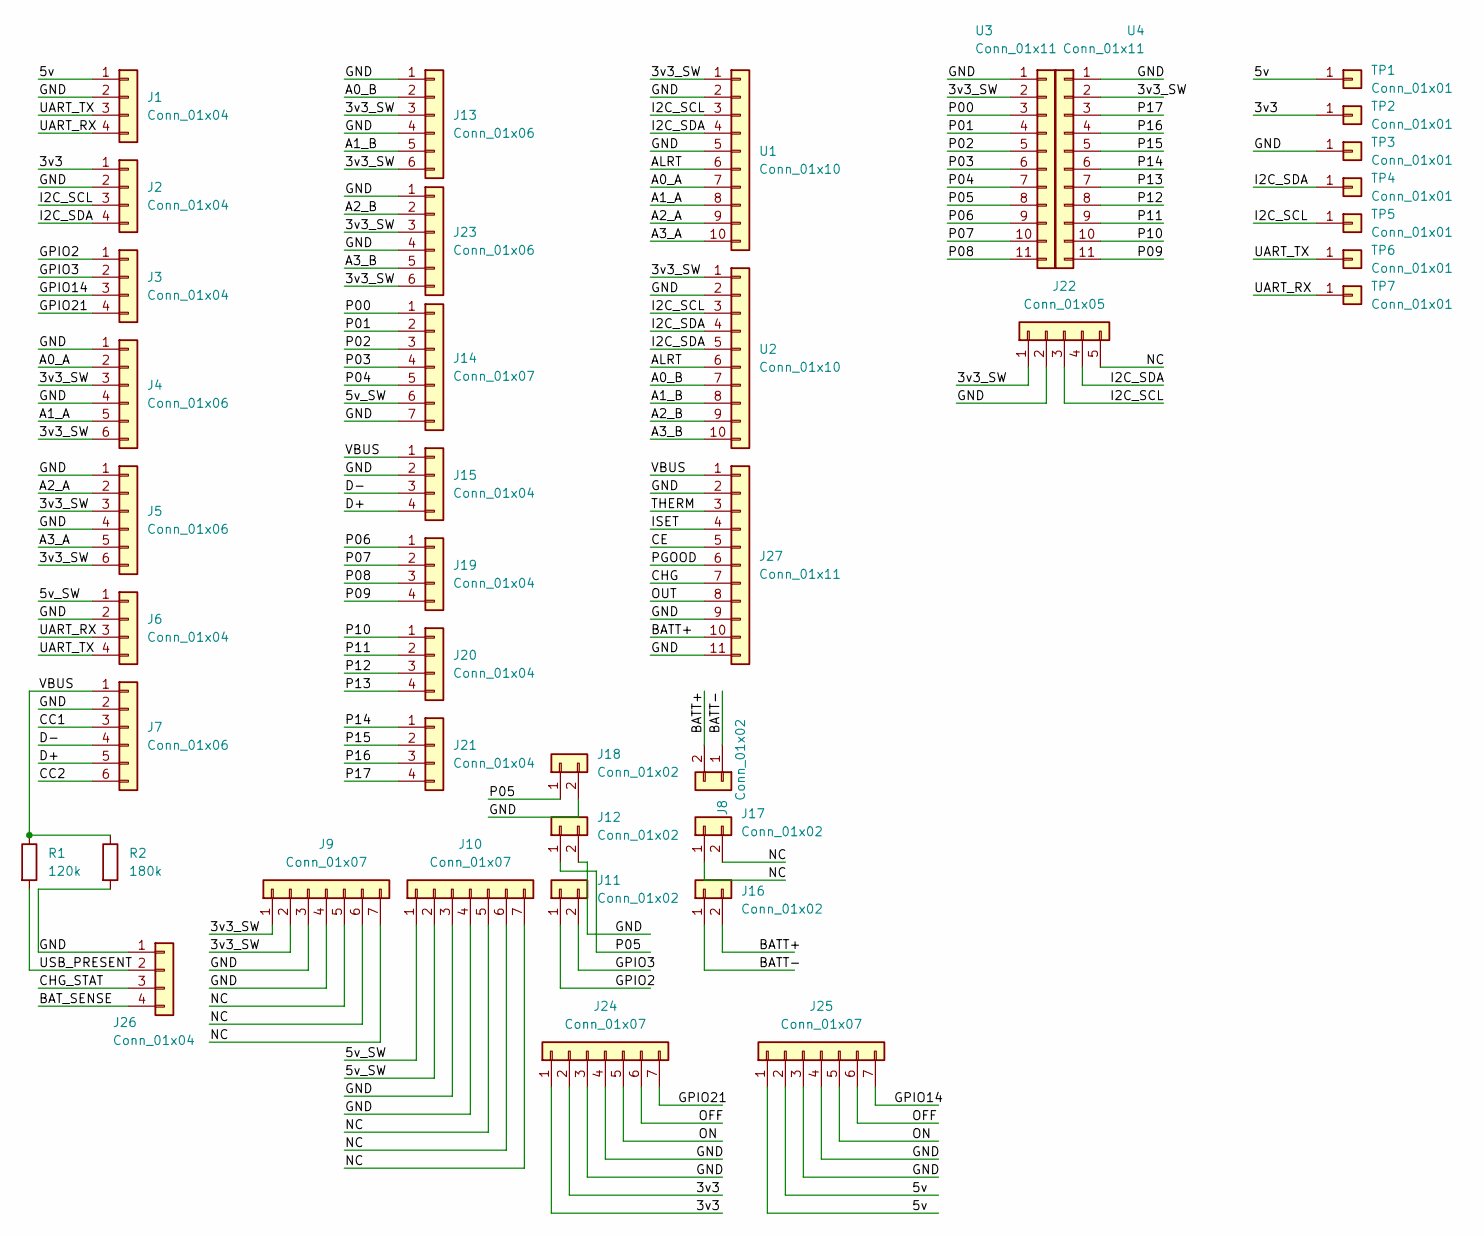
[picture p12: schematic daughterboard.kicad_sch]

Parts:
J1, J2, J3, J6, J19, J20, J21: Conn_01x04; PinHeader_1x04_P1.00mm_Horizontal
J4, J5, J13, J23: Conn_01x06; PinHeader_1x06_P1.00mm_Horizontal
J7: Conn_01x06; PinHeader_1x06_P2.54mm_Vertical
J8, J16: Conn_01x02; JST_PH_B2B-PH-K_1x02_P2.00mm_Vertical
J9, J10, J14, J24, J25: Conn_01x07; PinHeader_1x07_P2.54mm_Vertical
J11, J12, J18: Conn_01x02; PinHeader_1x02_P1.00mm_Horizontal
J15, J26: Conn_01x04; PinHeader_1x04_P2.54mm_Vertical
J17: Conn_01x02; PinHeader_1x02_P2.54mm_Vertical
J22: Conn_01x05; PinHeader_1x05_P2.54mm_Vertical
J27: Conn_01x11; PinHeader_1x11_P2.54mm_Vertical
R1: 120k; R_Axial_DIN0207_L6.3mm_D2.5mm_P7.62mm_Horizontal
R2: 180k; R_Axial_DIN0207_L6.3mm_D2.5mm_P7.62mm_Horizontal
TP1, TP2, TP3, TP4, TP5, TP6, TP7: Conn_01x01; TestPoint_Pad_D1.5mm
U1, U2: Conn_01x10; PinHeader_1x10_P2.54mm_Vertical
U3, U4: Conn_01x11; PinHeader_1x11_P2.54mm_Vertical

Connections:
/3v3: J2.1, J24.1, J24.2, TP2.1 (Pin_1_1)
/3v3_SW: J4.3, J4.6, J5.3, J5.6, J9.1, J9.2, J13.3, J13.6, J22.1, J23.3, J23.6, U1.1, U2.1, U3.2, U4.2
/5v: J1.1, J25.1, J25.2, TP1.1 (Pin_1_1)
/5v_SW: J6.1, J10.1, J10.2, J14.6
/A0_A: J4.2, U1.7
/A0_B: J13.2, U2.7
/A1_A: J4.5, U1.8
/A1_B: J13.5, U2.8
/A2_A: J5.2, U1.9
/A2_B: J23.2, U2.9
/A3_A: J5.5, U1.10
/A3_B: J23.5, U2.10
/ALRT: U1.6, U2.6
/BATT+: J8.2, J16.2, J27.10
/BATT-: J8.1, J16.1
/BAT_SENSE: J26.4
/CC1: J7.3
/CC2: J7.6
/CE: J27.5
/CHG: J27.7
/CHG_STAT: J26.3
/D+: J7.5, J15.4
/D-: J7.4, J15.3
/GND: J1.2, J2.2, J4.1, J4.4, J5.1, J5.4, J6.2, J7.2, J9.3, J9.4, J10.3, J10.4, J12.2, J13.1, J13.4, J14.7, J15.2, J18.2, J22.2, J23.1, J23.4, J24.3, J24.4, J25.3, J25.4, J26.1, J27.2, J27.9, J27.11, R2.2, TP3.1 (Pin_1_1), U1.2, U1.5, U2.2, U3.1, U4.1
/GPIO2: J3.1, J11.1
/GPIO3: J3.2, J11.2
/GPIO14: J3.3, J25.7
/GPIO21: J3.4, J24.7
/I2C_SCL: J2.3, J22.3, TP5.1 (Pin_1_1), U1.3, U2.3
/I2C_SDA: J2.4, J22.4, TP4.1 (Pin_1_1), U1.4, U2.4, U2.5
/ISET: J27.4
/NC: J9.5, J9.6, J9.7, J10.5, J10.6, J10.7, J17.1, J17.2, J22.5
/OFF: J24.6, J25.6
/ON: J24.5, J25.5
/OUT: J27.8
/P00: J14.1, U3.3
/P01: J14.2, U3.4
/P02: J14.3, U3.5
/P03: J14.4, U3.6
/P04: J14.5, U3.7
/P05: J12.1, J18.1, U3.8
/P06: J19.1, U3.9
/P07: J19.2, U3.10
/P08: J19.3, U3.11
/P09: J19.4, U4.11
/P10: J20.1, U4.10
/P11: J20.2, U4.9
/P12: J20.3, U4.8
/P13: J20.4, U4.7
/P14: J21.1, U4.6
/P15: J21.2, U4.5
/P16: J21.3, U4.4
/P17: J21.4, U4.3
/PGOOD: J27.6
/THERM: J27.3
/UART_RX: J1.4, J6.3, TP7.1 (Pin_1_1)
/UART_TX: J1.3, J6.4, TP6.1 (Pin_1_1)
/USB_PRESENT: J26.2, R1.2
/VBUS: J7.1, J15.1, J27.1, R1.1, R2.1

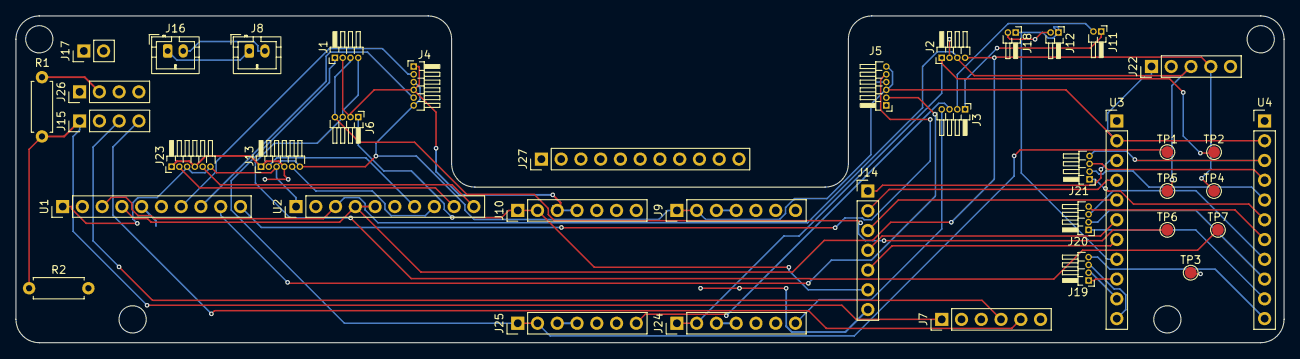
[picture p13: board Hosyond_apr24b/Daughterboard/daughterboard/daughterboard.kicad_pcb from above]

Board: 2 copper layers, 163.0 x 42.0 mm, 40 parts (0 on the bottom side), 49 nets.

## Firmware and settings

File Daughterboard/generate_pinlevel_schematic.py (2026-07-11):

from __future__ import annotations

import csv
from urllib.parse import quote_plus
import uuid
from dataclasses import dataclass
from pathlib import Path


ROOT_UUID = "d4b0641a-9c05-4a64-9f99-e24c4b75c101"
PROJECT = "Daughterboard"
LAYOUT_SCALE_X = 1.3
LAYOUT_SCALE_Y = 1.2


def uid() -> str:
    return str(uuid.uuid4())


@dataclass(frozen=True)
class Pin:
    number: str
    name: str
    side: str
    offset: float
    kind: str = "passive"


@dataclass(frozen=True)
class SymbolDef:
    name: str
    ref_prefix: str
    value: str
    footprint: str
    datasheet: str
    description: str
    width: float
    height: float
    pins: tuple[Pin, ...]
    in_bom: bool = True
    on_board: bool = True


@dataclass(frozen=True)
class Part:
    symbol: str
    ref: str
    value: str
    footprint: str
    x: float
    y: float
    nets: dict[str, str | None]
    datasheet: str = ""
    description: str = ""
    section: str = ""
    notes: str = ""
    in_bom: bool = True
    on_board: bool = True


def q(text: str) -> str:
    return text.replace("\\", "\\\\").replace('"', '\\"')


def snap(num: float) -> float:
    return round(num / 1.27) * 1.27


def fmt(num: float) -> str:
    num = snap(num)
    return f"{num:.3f}".rstrip("0").rstrip(".")


def prop(name: str, value: str, x: float, y: float, hide: bool = False) -> str:
    hide_s = " (hide yes)" if hide else ""
    return (
        f'\t\t(property "{q(name)}" "{q(value)}"\n'
        f"\t\t\t(at {fmt(x)} {fmt(y)} 0)\n"
        f"\t\t\t(effects (font (size 1.016 1.016)){hide_s} (justify left))\n"
        "\t\t)\n"
    )


def pin_xy(sym: SymbolDef, pin: Pin) -> tuple[float, float, int]:
    hw = sym.width / 2
    hh = sym.height / 2
    if pin.side == "L":
        return snap(-hw - 5.08), snap(pin.offset), 0
    if pin.side == "R":
        return snap(hw + 5.08), snap(pin.offset), 180
    if pin.side == "T":
        return snap(pin.offset), snap(-hh - 5.08), 90
    if pin.side == "B":
        return snap(pin.offset), snap(hh + 5.08), 270
    raise ValueError(pin.side)


def stub_xy(sym: SymbolDef, pin: Pin, x: float, y: float) -> tuple[float, float]:
    px, py, _ = pin_xy(sym, pin)
    sx = x + px
    sy = y - py
    if pin.side == "L":
        return sx - 5.08, sy
    if pin.side == "R":
        return sx + 5.08, sy
    if pin.side == "T":
        return sx, sy - 5.08
    if pin.side == "B":
        return sx, sy + 5.08
    raise ValueError(pin.side)


def draw_pin(pin: Pin, sym: SymbolDef) -> str:
    x, y, angle = pin_xy(sym, pin)
    return (
        f"\t\t\t(pin {pin.kind} line\n"
        f"\t\t\t\t(at {fmt(x)} {fmt(y)} {angle})\n"
        "\t\t\t\t(length 5.08)\n"
        f'\t\t\t\t(name "{q(pin.name)}" (effects (font (size 1.016 1.016))))\n'
        f'\t\t\t\t(number "{q(pin.number)}" (effects (font (size 1.016 1.016))))\n'
        "\t\t\t)\n"
    )


def symbol_def(sym: SymbolDef, embedded: bool = True) -> str:
    name = f"Daughterboard:{sym.name}" if embedded else sym.name
    out = [
        f'\t\t(symbol "{name}"\n',
        "\t\t\t(exclude_from_sim no)\n",
        f"\t\t\t(in_bom {'yes' if sym.in_bom else 'no'})\n",
        f"\t\t\t(on_board {'yes' if sym.on_board else 'no'})\n",
        "\t\t\t(duplicate_pin_numbers_are_jumpers no)\n",
        f'\t\t\t(property "Reference" "{q(sym.ref_prefix)}"\n',
        f"\t\t\t\t(at {fmt(-sym.width / 2)} {fmt(-sym.height / 2 - 7.62)} 0)\n",
        "\t\t\t\t(effects (font (size 1.27 1.27)))\n",
        "\t\t\t)\n",
        f'\t\t\t(property "Value" "{q(sym.value)}"\n',
        f"\t\t\t\t(at {fmt(-sym.width / 2)} {fmt(sym.height / 2 + 7.62)} 0)\n",
        "\t\t\t\t(effects (font (size 1.27 1.27)))\n",
        "\t\t\t)\n",
        f'\t\t\t(property "Footprint" "{q(sym.footprint)}"\n',
        "\t\t\t\t(at 0 0 0)\n",
        "\t\t\t\t(effects (font (size 1.27 1.27)) (hide yes))\n",
        "\t\t\t)\n",
        f'\t\t\t(property "Datasheet" "{q(sym.datasheet)}"\n',
        "\t\t\t\t(at 0 0 0)\n",
        "\t\t\t\t(effects (font (size 1.27 1.27)) (hide yes))\n",
        "\t\t\t)\n",
        f'\t\t\t(property "Description" "{q(sym.description)}"\n',
        "\t\t\t\t(at 0 0 0)\n",
        "\t\t\t\t(effects (font (size 1.27 1.27)) (hide yes))\n",
        "\t\t\t)\n",
        f'\t\t\t(symbol "{sym.name}_0_1"\n',
        f"\t\t\t\t(rectangle (start {fmt(-sym.width / 2)} {fmt(-sym.height / 2)}) "
        f"(end {fmt(sym.width / 2)} {fmt(sym.height / 2)}) "
        "(stroke (width 0.254) (type default)) (fill (type background)))\n",
    ]
    if sym.width >= 20 and sym.height >= 15:
        out.extend(
            [
                f'\t\t\t\t(text "{q(sym.value)}"\n',
                "\t\t\t\t\t(at 0 0 0)\n",
                "\t\t\t\t\t(effects (font (size 1.27 1.27) (bold yes)))\n",
                "\t\t\t\t)\n",
            ]
        )
    out.extend(
        [
            "\t\t\t)\n",
            f'\t\t\t(symbol "{sym.name}_1_1"\n',
        ]
    )
    for pin in sym.pins:
        out.append(draw_pin(pin, sym))
    out.append("\t\t\t)\n")
    out.append("\t\t)\n")
    return "".join(out)


def part_instance(part: Part, sym: SymbolDef) -> str:
    x, y = part.x, part.y
    field_x = x - sym.width / 2
    field_y = y - sym.height / 2 - 8.89
    out = [
        "\t(symbol\n",
        f'\t\t(lib_id "Daughterboard:{part.symbol}")\n',
        f"\t\t(at {fmt(x)} {fmt(y)} 0)\n",
        "\t\t(unit 1)\n",
        "\t\t(exclude_from_sim no)\n",
        f"\t\t(in_bom {'yes' if part.in_bom else 'no'})\n",
        f"\t\t(on_board {'yes' if part.on_board else 'no'})\n",
        "\t\t(dnp no)\n",
        f'\t\t(uuid "{uid()}")\n',
        prop("Reference", part.ref, field_x, field_y),
        prop("Value", part.value, field_x, field_y + 2.54),
        prop("Footprint", part.footprint, x, y, True),
        prop("Datasheet", part.datasheet, x, y, True),
        prop("Purchase Link", purchase_link_for(part), x, y, True),
        "\t\t(instances\n",
        f'\t\t\t(project "{PROJECT}"\n',
        f'\t\t\t\t(path "/{ROOT_UUID}" (reference "{part.ref}") (unit 1))\n',
        "\t\t\t)\n",
        "\t\t)\n",
        "\t)\n",
    ]
    return "".join(out)


def wire_label(x1: float, y1: float, x2: float, y2: float, net: str, inline: bool = False) -> str:
    label_x = x2
    label_y = y2 if inline else y2 - 2.54
    if not inline and abs(y2 - y1) > abs(x2 - x1):
        label_x = x2 - 5.08
        label_y = y2
    wires = (
        f"\t(wire (pts (xy {fmt(x1)} {fmt(y1)}) (xy {fmt(x2)} {fmt(y2)})) "
        f'(stroke (width 0) (type default)) (uuid "{uid()}"))\n'
    )
    if (label_x, label_y) != (x2, y2):
        wires += (
            f"\t(wire (pts (xy {fmt(x2)} {fmt(y2)}) (xy {fmt(label_x)} {fmt(label_y)})) "
            f'(stroke (width 0) (type default)) (uuid "{uid()}"))\n'
        )
    return wires + (
        f'\t(global_label "{q(net)}"\n'
        "\t\t(shape bidirectional)\n"
        f"\t\t(at {fmt(label_x)} {fmt(label_y)} 0)\n"
        "\t\t(fields_autoplaced yes)\n"
        "\t\t(effects (font (size 0.889 0.889)))\n"
        f'\t\t(uuid "{uid()}")\n'
        f'\t\t(property "Intersheetrefs" "${{INTERSHEET_REFS}}" (at {fmt(label_x)} {fmt(label_y)} 0) (effects (font (size 0.889 0.889)) (hide yes)))\n'
        "\t)\n"
    )


def no_connect(x: float, y: float) -> str:
    return f'\t(no_connect (at {fmt(x)} {fmt(y)}) (uuid "{uid()}"))\n'


def digikey_search(query: str) -> str:
    return f"https://www.digikey.com/en/products/result?keywords={quote_plus(query)}"


def purchase_link_for(part: Part) -> str:
    ref = part.ref
    value = part.value
    footprint = part.footprint

    exact_by_ref = {
        "J1": digikey_search("GCT USB4125 USB-C receptacle 6 pin"),
        "J7": digikey_search("JST XH 3 pin horizontal S3B-XH-A"),
        "U1": digikey_search("BQ25887RGE"),
        "U2": "https://www.digikey.com/en/products/detail/texas-instruments/BQ28Z610DRZR-R1/11625468",
        "Q1": "https://jlcpcb.com/partdetail/TexasInstruments-CSD18502Q5B/C473915",
        "Q2": "https://jlcpcb.com/partdetail/TexasInstruments-CSD18502Q5B/C473915",
        "U3": digikey_search("AP63200WU"),
        "U4": digikey_search("AP63200WU"),
        "U7": digikey_search("MCP23017-E/SO"),
        "SW1": "https://www.pololu.com/product/2808",
        "SW2": "https://www.pololu.com/product/2808",
        "J4": digikey_search("SM05B-GHS-TB JST GH 5 position"),
    }
    if ref in exact_by_ref:
        return exact_by_ref[ref]

    if ref.startswith("J3") or ref.startswith("TP"):
        return ""
    if "solder pad" in value:
        return ""
    if "test pad" in value:
        return ""

    if ref in {"BT1", "BT2"}:
        return digikey_search("18650 battery holder single cell PCB")
    if ref in {"J2", "J5", "J6", "J8"}:
        positions = {"J2": "3", "J5": "4", "J6": "2", "J8": "10"}[ref]
        return digikey_search(f"2.54mm pin header vertical {positions} position")
    if ref in {"U5", "U6"}:
        return digikey_search("ADS1115IDGS")
    if ref == "U7":
        return digikey_search("MCP23017-E/SO")
    if ref in {"D4", "D5", "D6", "D7"}:
        return digikey_search("4 channel 3.3V ESD TVS array SOT-23-6")
    if ref.startswith("F"):
        return digikey_search(f"{value} resettable fuse PTC SMD")
    if ref.startswith("L"):
        return digikey_search(f"{value} shielded inductor SMD")
    if ref.startswith("D"):
        if "TVS" in value:
            return digikey_search(f"{value} SOD-323 TVS diode")
        return digikey_search(f"{value} 0603 LED")
    if ref.startswith("TH"):
        return digikey_search(f"{value} 0603 NTC thermistor")
    if ref.startswith("R"):
        if "TBD" in value:
            return digikey_search("0603 resistor 1%")
        return digikey_search(f"{value} {footprint or '0603'} resistor")
    if ref.startswith("C"):
        return digikey_search(f"{value} {footprint or 'SMD'} capacitor")

    if footprint:
        return digikey_search(f"{value} {footprint}")
    if value:
        return digikey_search(value)
    return ""


def make_symbols() -> dict[str, SymbolDef]:
    two = (
        Pin("1", "1", "L", 0),
        Pin("2", "2", "R", 0),
    )
    three = (
        Pin("1", "1", "R", -5.08),
        Pin("2", "2", "R", 0),
        Pin("3", "3", "R", 5.08),
    )
    return {
        "USB_C_SINK_GCT_6PAD": SymbolDef(
            "USB_C_SINK_GCT_6PAD",
            "J",
            "USB-C 5V sink",
            "",
            "https://www.usb.org/document-library/usb-type-cr-cable-and-connector-specification-release-24",
            "Power-only USB-C receptacle using the GCT USB4125 six-pad footprint.",
            20.32,
            30,
            (
                Pin("A9", "VBUS_A", "R", -10.16),
                Pin("B9", "VBUS_B", "R", -5.08),
                Pin("A12", "GND_A", "R", 5.08),
                Pin("B12", "GND_B", "R", 10.16),
                Pin("A5", "CC1", "L", -2.54),
                Pin("B5", "CC2", "L", 2.54),
                Pin("SH", "SHIELD", "L", 10.16),
            ),
        ),
        "TWO_PIN": SymbolDef("TWO_PIN", "X", "2-pin part", "", "", "Generic two-pin part.", 10.16, 7.62, two),
        "TESTPAD": SymbolDef("TESTPAD", "TP", "Test pad", "", "", "Single test pad.", 7.62, 5.08, (Pin("1", "PAD", "R", 0),)),
        "PWR_FLAG": SymbolDef("PWR_FLAG", "#FLG", "PWR_FLAG", "", "", "ERC power flag.", 7.62, 5.08, (Pin("1", "PWR", "R", 0, "power_out"),), False, False),
        "CONN_2": SymbolDef(
            "CONN_2",
            "J",
            "2-pin connector",
            "",
            "",
            "Generic 2-pin connector.",
            12.7,
            12.7,
            (
                Pin("1", "1", "R", -2.54),
                Pin("2", "2", "R", 2.54),
            ),
        ),
        "CONN_3": SymbolDef("CONN_3", "J", "3-pin connector", "", "", "Generic 3-pin connector.", 12.7, 17.78, three),
        "CONN_4": SymbolDef(
            "CONN_4",
            "J",
            "4-pin connector",
            "",
            "",
            "Generic 4-pin connector.",
            12.7,
            22.86,
            (
                Pin("1", "1", "R", -7.62),
                Pin("2", "2", "R", -2.54),
                Pin("3", "3", "R", 2.54),
                Pin("4", "4", "R", 7.62),
            ),
        ),
        "CONN_5": SymbolDef(
            "CONN_5",
            "J",
            "5-pin connector",
            "",
            "",
            "Generic 5-pin connector.",
            12.7,
            27.94,
            (
                Pin("1", "1", "R", -10.16),
                Pin("2", "2", "R", -5.08),
                Pin("3", "3", "R", 0),
                Pin("4", "4", "R", 5.08),
                Pin("5", "5", "R", 10.16),
            ),
        ),
        "CONN_9": SymbolDef(
            "CONN_9",
            "J",
            "9-pin connector",
            "",
            "",
            "Generic 9-pin connector.",
            15.24,
            50.8,
            (
                Pin("1", "1", "R", -20.32),
                Pin("2", "2", "R", -15.24),
                Pin("3", "3", "R", -10.16),
                Pin("4", "4", "R", -5.08),
                Pin("5", "5", "R", 0),
                Pin("6", "6", "R", 5.08),
                Pin("7", "7", "R", 10.16),
                Pin("8", "8", "R", 15.24),
                Pin("9", "9", "R", 20.32),
            ),
        ),
        "CONN_10": SymbolDef(
            "CONN_10",
            "J",
            "10-pin connector",
            "",
            "",
            "Generic 10-pin connector.",
            15.24,
            55.88,
            (
                Pin("1", "1", "R", -22.86),
                Pin("2", "2", "R", -17.78),
                Pin("3", "3", "R", -12.7),
                Pin("4", "4", "R", -7.62),
                Pin("5", "5", "R", -2.54),
                Pin("6", "6", "R", 2.54),
                Pin("7", "7", "R", 7.62),
                Pin("8", "8", "R", 12.7),
                Pin("9", "9", "R", 17.78),
                Pin("10", "10", "R", 22.86),
            ),
        ),
        "ESD_ARRAY_4CH": SymbolDef(
            "ESD_ARRAY_4CH",
            "D",
            "4ch GPIO ESD array",
            "Daughterboard:SOT-23-6_NoPad6",
            "",
            "Generic 4-channel low-capacitance TVS/ESD array for exposed 3.3V GPIO pads.",
            20.32,
            27.94,
            (
                Pin("1", "IO1", "L", -7.62),
                Pin("2", "IO2", "L", -2.54),
                Pin("3", "GND", "B", 0),
                Pin("4", "IO3", "R", -2.54),
                Pin("5", "IO4", "R", -7.62),
                Pin("6", "NC", "R", 7.62, "no_connect"),
            ),
        ),
        "POLOLU_2808": SymbolDef(
            "POLOLU_2808",
            "SW",
            "Pololu #2808",
            "",
            "https://www.pololu.com/product/2808",
            "Mini Pushbutton Power Switch LV module.",
            25.4,
            22.86,
            (
                Pin("1", "VIN", "L", -5.08),
                Pin("2", "VOUT", "R", -5.08),
                Pin("3", "GND", "L", 5.08),
                Pin("4", "CTRL", "R", 5.08),
            ),
        ),
        "BQ24074RGT": SymbolDef(
            "BQ24074RGT",
            "U",
            "BQ24074RGT",
            "Package_DFN_QFN:VQFN-16-1EP_3x3mm_P0.5mm_EP1.6x1.6mm",
            "https://www.ti.com/lit/ds/symlink/bq24074.pdf",
            "USB-friendly 1-cell Li-ion charger with power-path management.",
            30,
            50,
            (
                Pin("13", "IN", "L", -20.32),
                Pin("4", "~{CE}", "L", -15.24),
                Pin("5", "EN2", "L", -10.16),
                Pin("6", "EN1", "L", -5.08),
                Pin("12", "ILIM", "L", 0),
                Pin("16", "ISET", "L", 5.08),
                Pin("14", "TMR", "L", 10.16),
                Pin("15", "ITERM", "L", 15.24),
                Pin("1", "TS", "R", -20.32),
                Pin("2", "BAT", "R", -15.24),
                Pin("3", "BAT", "R", -10.16),
                Pin("10", "OUT", "R", -5.08),
                Pin("11", "OUT", "R", 0),
                Pin("7", "~{PGOOD}", "R", 5.08),
                Pin("9", "~{CHG}", "R", 10.16),
                Pin("8", "VSS", "R", 15.24),
                Pin("17", "EP/VSS", "R", 20.32),
            ),
        ),
        "BQ25887RGE": SymbolDef(
            "BQ25887RGE",
            "U",
            "BQ25887RGE",
            "Package_DFN_QFN:Texas_RGE0024H_VQFN-24-1EP_4x4mm_P0.5mm_EP2.7x2.7mm",
            "https://www.ti.com/lit/ds/symlink/bq25887.pdf",
            "I2C-controlled 2-cell Li-ion/LiPo boost-mode USB charger with cell balancing.",
            40,
            70,
            (
                Pin("23", "VBUS", "L", -30.48, "power_in"),
                Pin("24", "PSEL", "L", -25.4),
                Pin("3", "CD", "L", -20.32),
                Pin("4", "SDA", "L", -15.24),
                Pin("5", "SCL", "L", -10.16),
                Pin("6", "~{INT}", "L", -5.08, "open_collector"),
                Pin("1", "~{PG}", "L", 0, "open_collector"),
                Pin("2", "STAT", "L", 5.08, "open_collector"),
                Pin("8", "ILIM", "L", 10.16),
                Pin("15", "SNS1", "L", 15.24),
                Pin("16", "SNS2", "L", 20.32),
                Pin("7", "TS", "R", -30.48),
                Pin("10", "CBSET", "R", -25.4),
                Pin("11", "REGN", "R", -20.32, "power_out"),
                Pin("12", "BTST", "R", -15.24),
                Pin("21", "PMID1", "R", -10.16),
                Pin("22", "PMID2", "R", -5.08),
                Pin("17", "SW1", "R", 0),
                Pin("18", "SW2", "R", 5.08),
                Pin("13", "BAT1", "R", 10.16),
                Pin("14", "BAT2", "R", 15.24),
                Pin("9", "MID", "R", 20.32),
                Pin("19", "GND1", "B", -5.08, "power_in"),
                Pin("20", "GND2", "B", 0, "power_in"),
                Pin("25", "EP/GND", "B", 5.08, "power_in"),
            ),
        ),
        "BQ297xy": SymbolDef(
            "BQ297xy",
            "U",
            "BQ297xy",
            "Package_SON:WSON-6_1.5x1.5mm_P0.5mm",
            "https://www.ti.com/lit/ds/symlink/bq2970.pdf",
            "Single-cell Li-ion protection controller.",
            25.4,
            25,
            (
                Pin("1", "NC", "R", 0, "no_connect"),
                Pin("2", "Cout", "R", -7.62, "output"),
                Pin("3", "Dout", "R", -2.54, "output"),
                Pin("4", "VSS", "B", 0, "power_in"),
                Pin("5", "BAT", "L", -2.54),
                Pin("6", "V-", "L", 7.62),
            ),
        ),
        "S8252A_M6": SymbolDef(
            "S8252A_M6",
            "U",
            "S-8252A",
            "Package_TO_SOT_SMD:SOT-23-6",
            "https://www.ablic.com/en/doc/datasheet/battery_protection/S8252_E.pdf",
            "ABLIC 2-serial-cell Li-ion/Li-polymer battery protection IC, SOT-23-6.",
            30.48,
            30.48,
            (
                Pin("1", "DO", "R", -10.16, "output"),
                Pin("2", "CO", "R", -5.08, "output"),
                Pin("3", "VM", "R", 5.08),
                Pin("4", "VC", "L", 0),
                Pin("5", "VDD", "L", -7.62, "power_in"),
                Pin("6", "VSS", "L", 7.62, "power_in"),
            ),
        ),
        "BQ28Z610_DRZ": SymbolDef(
            "BQ28Z610_DRZ",
            "U",
            "BQ28Z610DRZR-R1",
            "Daughterboard:BQ28Z610_DRZ0012A_12SON_2.5x4mm_P0.5mm",
            "https://www.ti.com/lit/ds/symlink/bq28z610.pdf",
            "TI 1S/2S Li-ion Impedance Track gas gauge and primary protection controller, DRZ0012A VSON-12.",
            35.56,
            50.8,
            (
                Pin("1", "VSS", "L", -20.32, "power_in"),
                Pin("2", "SRN", "L", -15.24),
                Pin("3", "SRP", "L", -10.16),
                Pin("4", "TS1", "L", -5.08),
                Pin("5", "SCL", "L", 5.08, "input"),
                Pin("6", "SDA", "L", 10.16),
                Pin("7", "DSG", "R", -17.78, "output"),
                Pin("8", "PACK", "R", -10.16),
                Pin("9", "CHG", "R", -2.54, "output"),
                Pin("10", "PBI", "R", 5.08),
                Pin("11", "VC2", "R", 12.7, "power_in"),
                Pin("12", "VC1", "R", 17.78),
                Pin("13", "PWPD", "B", 0, "power_in"),
            ),
        ),
        "PROT_FET_PAIR": SymbolDef(
            "PROT_FET_PAIR",
            "Q",
            "CSD83325L",
            "Daughterboard:CSD83325L_YJE0006A",
            "https://www.ti.com/lit/ds/symlink/csd83325l.pdf",
            "12 V dual common-drain N-channel NexFET in TI YJE0006A PicoStar/LGA package.",
            30.48,
            30.48,
            (
                Pin("A1", "S1A", "L", -10.16),
                Pin("C1", "S1B", "L", -5.08),
                Pin("B1", "G1", "L", 5.08),
                Pin("A2", "S2A", "R", -10.16),
                Pin("C2", "S2B", "R", -5.08),
                Pin("B2", "G2", "R", 5.08),
            ),
        ),
        "CSD18502Q5B": SymbolDef(
            "CSD18502Q5B",
            "Q",
            "CSD18502Q5B",
            "Daughterboard:CSD18502Q5B_DNK0008A_VSON-CLIP_5x6mm",
            "https://www.ti.com/lit/ds/symlink/csd18502q5b.pdf",
            "40 V single N-channel NexFET in TI DNK/VSON-CLIP-8 package; JLCPCB C473915.",
            25.4,
            35.56,
            (
                Pin("1", "S", "L", -10.16),
                Pin("2", "S", "L", -5.08),
                Pin("3", "S", "L", 0),
                Pin("4", "G", "L", 7.62, "input"),
                Pin("5", "D", "R", -10.16),
                Pin("6", "D", "R", -5.08),
                Pin("7", "D", "R", 0),
                Pin("8", "D", "R", 5.08),
            ),
        ),
        "TPS61023": SymbolDef(
            "TPS61023",
            "U",
            "TPS61023",
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

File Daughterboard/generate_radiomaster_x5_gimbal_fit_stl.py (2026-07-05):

from __future__ import annotations

import math
from pathlib import Path


OUT = Path("radiomaster_x5_gimbal_fit_model.stl")

PLATE_W = 39.0
PLATE_W_AT_BUMP = 41.9
PLATE_H = 35.0
PLATE_T = 2.2
BUMP_H = 12.0
RIGHT_BUMP_W = PLATE_W_AT_BUMP - PLATE_W

STICK_OPENING_D = 37.0
CIRCULAR_SHROUD_H = 4.0
SHROUD_LIP_D = 34.2
SHROUD_LIP_H = 1.0
WINDOW_W = 24.0
WINDOW_H = 10.5
MOUNT_SPACING_X = 32.9
MOUNT_SPACING_Y = 30.0
MOUNTING_HOLE_D = 2.2
SCREW_BOSS_D = 6.1
SCREW_BOSS_H = 1.1

BODY_W = 34.0
BODY_H = 30.0
BODY_DEPTH = 23.0

STICK_SHAFT_D = 4.2
STICK_CAP_D = 8.6
STICK_CAP_H = 5.5
OVERALL_HEIGHT = 43.3
STICK_TOP_Z = OVERALL_HEIGHT - BODY_DEPTH
STICK_BASE_Z = PLATE_T + CIRCULAR_SHROUD_H + SHROUD_LIP_H
STICK_SHAFT_H = STICK_TOP_Z - STICK_BASE_Z - STICK_CAP_H

SEGMENTS = 96


def vsub(a, b):
    return (a[0] - b[0], a[1] - b[1], a[2] - b[2])


def cross(a, b):
    return (
        a[1] * b[2] - a[2] * b[1],
        a[2] * b[0] - a[0] * b[2],
        a[0] * b[1] - a[1] * b[0],
    )


def norm(a):
    length = math.sqrt(a[0] ** 2 + a[1] ** 2 + a[2] ** 2)
    if length == 0:
        return (0.0, 0.0, 0.0)
    return (a[0] / length, a[1] / length, a[2] / length)


def tri_normal(tri):
    return norm(cross(vsub(tri[1], tri[0]), vsub(tri[2], tri[0])))


def add_box(tris, cx, cy, cz, sx, sy, sz):
    x0, x1 = cx - sx / 2, cx + sx / 2
    y0, y1 = cy - sy / 2, cy + sy / 2
    z0, z1 = cz - sz / 2, cz + sz / 2
    p = {
        "000": (x0, y0, z0),
        "100": (x1, y0, z0),
        "110": (x1, y1, z0),
        "010": (x0, y1, z0),
        "001": (x0, y0, z1),
        "101": (x1, y0, z1),
        "111": (x1, y1, z1),
        "011": (x0, y1, z1),
    }
    faces = [
        ("bottom", ["000", "010", "110", "100"]),
        ("top", ["001", "101", "111", "011"]),
        ("front", ["000", "100", "101", "001"]),
        ("right", ["100", "110", "111", "101"]),
        ("back", ["110", "010", "011", "111"]),
        ("left", ["010", "000", "001", "011"]),
    ]
    for _, keys in faces:
        a, b, c, d = [p[k] for k in keys]
        tris.append((a, b, c))
        tris.append((a, c, d))


def add_cylinder(tris, cx, cy, z0, z1, radius, segments=SEGMENTS):
    top_center = (cx, cy, z1)
    bottom_center = (cx, cy, z0)
    for i in range(segments):
        a0 = 2 * math.pi * i / segments
        a1 = 2 * math.pi * (i + 1) / segments
        p0 = (cx + radius * math.cos(a0), cy + radius * math.sin(a0), z0)
        p1 = (cx + radius * math.cos(a1), cy + radius * math.sin(a1), z0)
        p2 = (cx + radius * math.cos(a1), cy + radius * math.sin(a1), z1)
        p3 = (cx + radius * math.cos(a0), cy + radius * math.sin(a0), z1)
        tris.append((p0, p1, p2))
        tris.append((p0, p2, p3))
        tris.append((top_center, p3, p2))
        tris.append((bottom_center, p1, p0))


def add_slotted_disk_grid(tris, z0, z1, radius, slot_w, slot_h, step=0.5):
    cells = set()
    count = int(math.ceil((radius * 2) / step))
    min_xy = -count * step / 2
    for ix in range(count):
        for iy in range(count):
            cx = min_xy + (ix + 0.5) * step
            cy = min_xy + (iy + 0.5) * step
            in_circle = cx * cx + cy * cy <= radius * radius
            in_slot = abs(cx) <= slot_w / 2 and abs(cy) <= slot_h / 2
            if in_circle and not in_slot:
                cells.add((ix, iy))

    def pt(ix, iy, z):
        return (min_xy + ix * step, min_xy + iy * step, z)

    for ix, iy in cells:
        p00 = pt(ix, iy, z0)
        p10 = pt(ix + 1, iy, z0)
        p11 = pt(ix + 1, iy + 1, z0)
        p01 = pt(ix, iy + 1, z0)
        q00 = pt(ix, iy, z1)
        q10 = pt(ix + 1, iy, z1)
        q11 = pt(ix + 1, iy + 1, z1)
        q01 = pt(ix, iy + 1, z1)

        tris.append((q00, q10, q11))
        tris.append((q00, q11, q01))
        tris.append((p00, p11, p10))
        tris.append((p00, p01, p11))

        neighbors = [
            ((ix, iy - 1), (p00, p10, q10, q00)),
            ((ix + 1, iy), (p10, p11, q11, q10)),
            ((ix, iy + 1), (p11, p01, q01, q11)),
            ((ix - 1, iy), (p01, p00, q00, q01)),
        ]
        for neighbor, quad in neighbors:
            if neighbor not in cells:
                a, b, c, d = quad
                tris.append((a, b, c))
                tris.append((a, c, d))


def ring_points(cx, cy, r, z, segments=SEGMENTS):
    return [
        (cx + r * math.cos(2 * math.pi * i / segments), cy + r * math.sin(2 * math.pi * i / segments), z)
        for i in range(segments)
    ]


def add_mount_hole_markers(tris):
    # Through-hole voids are represented by clearance cylinders colored by geometry only in STL.
    # The plate is primarily a fit-check visual mesh; edit SCAD for true CSG if needed.
    for x in (-MOUNT_SPACING_X / 2, MOUNT_SPACING_X / 2):
        for y in (-MOUNT_SPACING_Y / 2, MOUNT_SPACING_Y / 2):
            add_cylinder(tris, x, y, PLATE_T, PLATE_T + 0.35, MOUNTING_HOLE_D / 2)


def add_screw_bosses(tris):
    for x in (-MOUNT_SPACING_X / 2, MOUNT_SPACING_X / 2):
        for y in (-MOUNT_SPACING_Y / 2, MOUNT_SPACING_Y / 2):
            add_cylinder(tris, x, y, PLATE_T, PLATE_T + SCREW_BOSS_H, SCREW_BOSS_D / 2)


def write_stl(path, tris):
    with path.open("w", newline="\n") as fh:
        fh.write("solid radiomaster_x5_gimbal_fit_model\n")
        for tri in tris:
            n = tri_normal(tri)
            fh.write(f"  facet normal {n[0]:.6g} {n[1]:.6g} {n[2]:.6g}\n")
            fh.write("    outer loop\n")
            for p in tri:
                fh.write(f"      vertex {p[0]:.6g} {p[1]:.6g} {p[2]:.6g}\n")
            fh.write("    endloop\n")
            fh.write("  endfacet\n")
        fh.write("endsolid radiomaster_x5_gimbal_fit_model\n")
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

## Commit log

2026-07-05 remove old files
    [Hosyond_carrier_connector_inventory.csv, Hosyond_carrier_kicad_label_checklist.csv, Hosyond_carrier_net_table.csv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]
2026-07-08 rep update
    [.step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]
2026-07-10 R13 update
    [Daughterboard-B_Cu.gbl, Daughterboard-B_Mask.gbs, Daughterboard-B_Paste.gbp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]
2026-07-13 R15 Files
    [2_Daughterboard_r15_BOM.csv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]
